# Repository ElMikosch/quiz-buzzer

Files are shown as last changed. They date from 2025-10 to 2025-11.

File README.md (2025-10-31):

# Quiz Buzzer System

A distributed ESP32-based quiz buzzer system with 4 wireless buzzer nodes and a main controller for quiz game management.

## Features

- **4 Independent Buzzer Nodes**: Wireless ESP32-based buttons with LED feedback
- **First-Press Detection**: Reliable distributed timing across all buzzers
- **Game State Management**: Ready, locked, and partial-lockout states
- **Auto-Reconnection**: Automatic state recovery after power cycle or network issues
- **Connection Monitoring**: Heartbeat system detects disconnections within 5 seconds
- **Answer Validation**: Correct/wrong/reset controls for game host
- **PC Integration**: USB serial interface (115200 baud) for quiz software
- **Visual Feedback**: LED states (solid=ready, blink=selected, off=locked, rapid blink=disconnected)
- **Low Latency**: Sub-100ms response time via ESP-NOW protocol
- **Battery Powered Buzzers**: ~4-6 hours operation with light sleep mode

## Hardware

- 5x Lolin32 Lite (ESP32) boards
- 7x Push buttons
- 4x LEDs with resistors
- 4x 1100mAh 3.7V LiPo batteries
- 1x USB cable

## Quick Start

### 1. Flash Firmware
```bash
# Flash main controller
pio run -e main_controller -t upload

# Flash each buzzer node
pio run -e buzzer_node_1 -t upload
pio run -e buzzer_node_2 -t upload
pio run -e buzzer_node_3 -t upload
pio run -e buzzer_node_4 -t upload
```

### 2. Label Boards
Physically label each board after flashing:
- Main controller: "MAIN"
- Buzzer nodes: "Buzzer 1" through "Buzzer 4"

### 3. Test System
1. Power main controller first
2. Power all buzzer nodes
3. All LEDs should turn on (ready state)
4. Press any buzzer → that LED blinks, others turn off
5. Press CORRECT button → all LEDs turn on again

### 4. Connect to PC
```bash
# Linux/Mac
screen /dev/ttyUSB0 115200

# Windows
# Use PuTTY or Arduino Serial Monitor at 115200 baud
```

## Documentation

- **[GPIO Pins](docs/GPIO_PINS.md)** - Pin assignments and hardware requirements
- **[Protocols](docs/PROTOCOLS.md)** - ESP-NOW and USB Serial protocols
- **[State Machine](docs/STATE_MACHINE.md)** - Game states and transitions
- **[Deployment](docs/DEPLOYMENT.md)** - Full deployment and troubleshooting guide

## PC Interface

### Outbound Messages (Controller → PC)

Messages sent over USB serial (newline-terminated):
```
BUZZER:1      # Buzzer 1 pressed
BUZZER:2      # Buzzer 2 pressed
BUZZER:3      # Buzzer 3 pressed
BUZZER:4      # Buzzer 4 pressed
CORRECT       # Correct answer button pressed
WRONG         # Wrong answer button pressed
RESET         # Reset button pressed
DISCONNECT:2  # Buzzer 2 disconnected
RECONNECT:2   # Buzzer 2 reconnected
```

### Inbound Commands (PC → Controller)

Send commands to control the game from your PC:
```
CORRECT\n     # Mark answer correct and reset game
WRONG\n       # Mark answer wrong and lock out current buzzer
RESET\n       # Full reset of game state
```

Command responses:
```
CMD_ACK:CORRECT           # Command acknowledged and executed
CMD_ACK:WRONG             # Command acknowledged and executed
CMD_ACK:RESET             # Command acknowledged and executed
CMD_ERR:UNKNOWN:FOO       # Unknown command "FOO"
CMD_ERR:BUFFER_OVERFLOW   # Input exceeded 256 bytes
```

### Example: Reading Messages
```python
import serial
ser = serial.Serial('/dev/ttyUSB0', 115200)
while True:
    line = ser.readline().decode().strip()
    if line.startswith('BUZZER:'):
        buzzer_id = int(line.split(':')[1])
        print(f"Buzzer {buzzer_id} pressed!")
    elif line == 'CORRECT':
        print("Correct answer!")
```

### Example: Sending Commands
```python
import serial
ser = serial.Serial('/dev/ttyUSB0', 115200)

# Mark answer correct
ser.write(b'CORRECT\n')
response = ser.readline().decode().strip()
print(response)  # CMD_ACK:CORRECT

# Mark answer wrong
ser.write(b'WRONG\n')
response = ser.readline().decode().strip()
print(response)  # CMD_ACK:WRONG

# Reset game
ser.write(b'RESET\n')
response = ser.readline().decode().strip()
print(response)  # CMD_ACK:RESET
```

### Using with Serial Terminal
```bash
# Linux/Mac - using screen
screen /dev/ttyUSB0 115200
# Type commands: CORRECT, WRONG, or RESET followed by Enter

# Alternative - using echo
echo "CORRECT" > /dev/ttyUSB0

# Windows PowerShell
"CORRECT`n" | Out-File -FilePath COM3 -Encoding ASCII -NoNewline
```

**Note**: Serial commands work identically to physical button presses and can be used concurrently.

## Project Structure

```
quiz-buzzer/
├── src/
│   ├── buzzer_node.cpp    # Buzzer node firmware
│   ├── controller.cpp     # Main controller firmware
│   ├── protocol.h         # Shared message protocol
│   ├── config.h           # Pin assignments and constants
│   └── main.cpp           # Entry point (empty, routing via platformio.ini)
├── docs/
│   ├── GPIO_PINS.md       # Hardware pin assignments
│   ├── PROTOCOLS.md       # Communication protocols
│   ├── STATE_MACHINE.md   # Game state documentation
│   └── DEPLOYMENT.md      # Deployment and troubleshooting
├── openspec/              # Design proposals and specs
└── platformio.ini         # Build configurations
```

## Building

### Prerequisites
- [PlatformIO](https://platformio.org/install)
- USB drivers for Lolin32 Lite (CH340 or CP2102)

### Build Commands
```bash
# Build all environments
pio run

# Build specific environment
pio run -e main_controller
pio run -e buzzer_node_1

# Build and upload
pio run -e main_controller -t upload

# Monitor serial output
pio device monitor -e main_controller
```

## Troubleshooting

### Buzzer LEDs Not Responding
- Verify custom MAC addresses in serial output (AA:BB:CC:DD:EE:00-04)
- Check ESP-NOW initialization messages
- Ensure main controller powered first
- Reduce distance between boards

### Button Presses Not Detected
- Test button continuity with multimeter
- Check GPIO pin assignments match wiring
- Verify internal pullups enabled (default)

### No Serial Messages to PC
- Check baud rate is 115200
- Verify USB drivers installed
- Check serial port permissions (Linux: add user to `dialout` group)
- Ensure main controller receiving buzzer presses (check local serial)

### Buzzer Shows Rapid Blinking (10Hz)
- This indicates disconnection from main controller
- Check main controller is powered and running
- Verify both devices on same WiFi channel (channel 1)
- Move buzzer closer to main controller (within ~20m)
- Check serial output on main controller for `DISCONNECT:<id>` messages
- Buzzer will auto-reconnect when heartbeat resumes

### Buzzer Reconnects But Wrong LED State
- System automatically syncs state on reconnection
- Check serial output for `STATE_SYNC` messages
- If issue persists, press RESET button on main controller to clear all state

### Build Errors
- Ensure PlatformIO is updated: `pio upgrade`
- Clean build: `pio run -t clean`
- Check that correct environment is selected

See **[docs/DEPLOYMENT.md](docs/DEPLOYMENT.md)** for detailed troubleshooting.

## Future Enhancements

- [ ] Speaker audio feedback on buzzer nodes (GPIO 14 reserved)
- [ ] Low battery voltage monitoring
- [ ] Visual display screen
- [ ] Over-the-air (OTA) firmware updates
- [ ] DIP switch node ID configuration
- [ ] Auto-discovery of buzzer nodes

## License

MIT License - See LICENSE file for details

## Contributing

This project uses OpenSpec for change proposals. See `openspec/AGENTS.md` for guidelines on creating proposals.

## Support

For issues and questions, open an issue on GitHub.

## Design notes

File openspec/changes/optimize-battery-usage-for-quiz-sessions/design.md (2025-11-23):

# Technical Design: Battery Usage Optimization

## Context

The quiz buzzer system runs on battery-powered ESP32 nodes that must operate throughout quiz sessions (30-60 minutes typical). Current implementation consumes excessive power due to:
- Full-speed CPU operation (240MHz)
- Always-active WiFi without modem sleep
- Continuous polling loop with minimal delay (1ms)
- No sleep modes between operations

Human reaction time (150-300ms average, 100ms for fast reflexes) provides headroom for modest latency additions while maintaining quiz fairness. Commercial quiz systems typically have 20-50ms latency; we target <50ms to stay competitive while optimizing battery life.

## Goals / Non-Goals

**Goals:**
- Reduce power consumption by 50-70% during active quiz sessions
- Maintain button press response time <50ms for fairness
- Ensure equal latency across all nodes (±5ms variance)
- Extend battery life from hours to full-day operation
- Preserve all existing functionality and LED behaviors

**Non-Goals:**
- Deep sleep modes (incompatible with sub-second response requirements)
- Battery monitoring/fuel gauge (future enhancement)
- Dynamic heartbeat adjustment based on activity
- Power optimization for main controller (remains USB-powered)
- Adaptive power modes based on battery level

## Decisions

### Decision 1: Light Sleep Instead of Deep Sleep
**Choice:** Use ESP32 light sleep mode with GPIO wake on button press.

**Rationale:**
- Light sleep wakes in ~3-5ms vs deep sleep's 100-300ms
- GPIO interrupt wake provides immediate response to button press
- WiFi and ESP-NOW connection state preserved (no reconnection delay)
- Timer wake allows periodic processing (LED updates, heartbeat checks)

**Alternatives considered:**
- Deep sleep: Rejected due to 100-300ms wake time violating <50ms requirement
- No sleep: Current approach, unacceptable battery consumption
- Active waiting with yield(): Minimal power savings compared to light sleep

### Decision 2: CPU Frequency Reduction to 80MHz
**Choice:** Reduce CPU from default 240MHz to 80MHz.

**Rationale:**
- ESP32 power consumption scales roughly linearly with frequency
- 80MHz provides 66% reduction from 240MHz (saves ~40% CPU power)
- More than adequate for simple embedded logic (GPIO, ESP-NOW, PWM)
- Arduino timing functions (millis/micros) remain accurate
- ESP-NOW and WiFi drivers work correctly at 80MHz

**Alternatives considered:**
- 160MHz: Less power savings, no performance benefit needed
- 40MHz: Potential WiFi/ESP-NOW reliability issues
- Dynamic scaling: Added complexity without clear benefit for this use case

### Decision 3: WiFi Modem Sleep Mode
**Choice:** Enable `WIFI_PS_MIN_MODEM` power save mode.

**Rationale:**
- WiFi radio is largest power consumer on ESP32
- Modem sleep shuts down RF between packets while maintaining connection
- Automatic wake on ESP-NOW TX/RX (transparent to application)
- Adds 5-10ms latency (acceptable within 50ms budget)
- No code changes needed beyond configuration call

**Alternatives considered:**
- `WIFI_PS_MAX_MODEM`: More aggressive sleep, but can cause packet loss
- `WIFI_PS_NONE`: Current default, no power savings
- Disable WiFi between heartbeats: Complex state management, connection reliability issues

### Decision 4: Dynamic Power Modes Based on Game State
**Choice:** Implement three power modes with different sleep durations:
- **ACTIVE** (ready state): 50ms sleep, GPIO wake enabled
- **LOW_POWER** (locked out): 100ms sleep, GPIO wake disabled
- **MINIMAL** (disconnected): 200ms sleep, GPIO wake disabled

**Rationale:**
- Ready state needs fast response, justify shorter sleep (50ms)
- Locked/disconnected states can sleep longer (button inactive)
- Breathing LED fade (20ms updates) works fine with 200ms wake interval
- State transitions occur naturally with LED commands
- Significant power savings during non-active periods

**Alternatives considered:**
- Single sleep duration: Misses optimization opportunity during locked/disconnected
- Five+ power modes: Complexity without proportional benefit
- Activity-based adaptation: Over-engineered for predictable quiz usage patterns

### Decision 5: Timer Wake as Fallback to GPIO Wake
**Choice:** Always configure both GPIO wake (button) and timer wake (backup) for light sleep.

**Rationale:**
- GPIO wake handles button presses immediately (<5ms)
- Timer wake ensures periodic processing even if no button press
- Required for LED updates (blink/fade), heartbeat monitoring, ESP-NOW RX
- 50ms timer wake in ready state ensures <50ms worst-case button latency
- Longer timers (100-200ms) acceptable when button inactive

**Alternatives considered:**
- GPIO wake only: Would miss heartbeats and LED updates
- Timer wake only: Higher power consumption, slower button response
- Event-driven ESP-NOW wake: Not reliably supported in light sleep

## Architecture

### Power State Machine

```
           [Startup]
               |
               v
        [MINIMAL MODE]
        LED: breathing
        Sleep: 200ms
        GPIO wake: disabled
               |
               | (receive heartbeat + state sync → ready)
               v
        [ACTIVE MODE] <----------+
        LED: solid on            |
        Sleep: 50ms              |
        GPIO wake: enabled       | (reset/correct button)
               |                 |
               | (wrong answer / locked out)
               v                 |
        [LOW_POWER MODE]         |
        LED: off                 |
        Sleep: 100ms             |
        GPIO wake: disabled -----+
```

### Loop Execution Flow

```
loop() iteration:
1. Check connection (heartbeat timeout)
2. Handle button press (if GPIO wake triggered)
3. Update LED (blink/fade state machine)
4. Determine current power mode from LED state
5. Configure sleep (GPIO + timer wake sources)
6. Enter light sleep
7. Wake on button press OR timer expiry
8. Repeat
```

### Timing Budget Analysis

| Operation | Time (ms) | Notes |
|---|---|---|
| Light sleep wake | 3-5 | GPIO interrupt wake |
| Button debounce | 0-50 | Max debounce delay |
| ESP-NOW transmission | 5-10 | With modem sleep wake |
| Loop processing overhead | 1-2 | GPIO read, LED update |
| **Total worst case** | **59-67** | **Exceeds 50ms target** |

**Mitigation:** Reduce debounce delay from 50ms to 30ms in active mode, bringing total to 39-47ms.

## Risks / Trade-offs

### Risk 1: Light Sleep Compatibility with ESP-NOW Reception
**Risk:** ESP-NOW messages might not reliably wake ESP32 from light sleep.

**Mitigation:** 
- Timer wake every 50ms ensures messages processed within reasonable time
- Heartbeat interval (2000ms) >> sleep duration (50ms), plenty of margin
- Test message reception reliability extensively during implementation

### Risk 2: Timing Variance Across Nodes
**Risk:** Power mode transitions could cause temporary timing differences between nodes.

**Mitigation:**
- All nodes transition together (synchronized by main controller LED commands)
- Test simultaneous button presses during state transitions
- Log timing measurements to verify fairness (±5ms target)

### Risk 3: PWM/LED Behavior at Reduced CPU Frequency
**Risk:** LED PWM might flicker or lose precision at 80MHz.

**Mitigation:**
- LEDC peripheral uses independent clock, not affected by CPU frequency
- Test all LED patterns (solid, blink, fade) after frequency change
- Measure PWM frequency/duty cycle with oscilloscope if issues arise

### Risk 4: Reduced Button Debounce Time
**Risk:** 30ms debounce might allow switch bounce through, causing double presses.

**Mitigation:**
- Test with all 4 physical buzzer buttons extensively
- Monitor serial logs for unexpected multiple presses within short time
- Can increase debounce if bounce detected (trade latency vs reliability)
- Add "burst suppression" (ignore presses within 100ms of previous press)

## Migration Plan

**Phase 1: Non-Breaking Power Optimizations**
1. Add CPU frequency scaling (always safe, test timing)
2. Enable WiFi modem sleep (transparent to application)
3. Add telemetry: log current measurements, button latency

**Phase 2: Light Sleep Implementation**
1. Add light sleep with conservative 50ms duration in all modes
2. Test button responsiveness and message reception
3. Monitor for any missed heartbeats or state sync issues

**Phase 3: Dynamic Power Modes**
1. Implement power mode state machine
2. Add longer sleep durations for locked/disconnected states
3. Test state transitions and timing fairness

**Rollback:** Each phase can be individually disabled via config constants if issues arise.

## Open Questions

1. **Optimal debounce time:** Is 30ms sufficient, or do we need 40-50ms? Requires hardware testing.
2. **Battery capacity selection:** What mAh capacity should be recommended for target full-day operation? Depends on measured power consumption.
3. **Sleep duration tuning:** Are 50/100/200ms optimal, or should we adjust based on measured latency? Will iterate during testing.
4. **Main controller optimization:** Should main controller also reduce CPU frequency (doesn't affect battery life but reduces heat)? Could add in future.

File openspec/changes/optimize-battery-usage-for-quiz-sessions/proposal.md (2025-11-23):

# Battery Usage Optimization for Quiz Sessions

## Why
The buzzer nodes run exclusively on battery power during quiz sessions, but currently consume excessive power due to always-active WiFi, full-speed CPU operation, and continuous polling loops. This results in short battery life and frequent recharging. However, human reaction times (150-300ms) and quiz system requirements allow for moderate latency (30-80ms) as long as the first button press is always detected correctly and fairly across all nodes.

## What Changes
- **Add light sleep mode** to buzzer nodes between loop iterations with GPIO interrupt wake on button press
- **Add CPU frequency scaling** from 240MHz to 80MHz during normal operation (40% less power)
- **Add WiFi modem sleep** to reduce power consumption between ESP-NOW transmissions
- **Add dynamic power modes** based on game state (ready vs locked/disconnected)
- **Maintain response time guarantee** of <50ms button press detection for quiz fairness
- **Add power state transitions** for entering/exiting low-power modes based on game events

## Impact
- **Affected specs**: buzzer-node, main-controller
- **Affected code**: 
  - `src/buzzer_node.cpp`: Add power management, sleep modes, interrupt handlers
  - `src/config.h`: Add power management constants and thresholds
  - `src/controller.cpp`: Optimize heartbeat timing for power efficiency
- **Expected outcomes**:
  - 50-70% reduction in power consumption during quiz sessions
  - Maintained <50ms button press response time (well within human reaction time variance)
  - Equal latency across all nodes preserving quiz fairness
  - Extended battery life from hours to full-day operation
- **Non-goals**:
  - Deep sleep modes (incompatible with sub-second wake requirements)
  - Battery monitoring/reporting (future enhancement)
  - Dynamic heartbeat adjustment (keep simple for v1)

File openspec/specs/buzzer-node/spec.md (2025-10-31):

# buzzer-node Specification

## Purpose
TBD - created by archiving change add-multi-board-buzzer-system. Update Purpose after archive.
## Requirements
### Requirement: Button Press Detection
Each buzzer node SHALL detect button press events with debouncing and transmit them to the main controller.

#### Scenario: Button press detected
- **WHEN** a player presses the buzzer button
- **THEN** the node SHALL debounce the input for 50ms
- **AND** transmit a button press message to the main controller
- **AND** include node ID (1-4) and timestamp in the message

#### Scenario: Button already pressed during lockout
- **WHEN** a player presses the buzzer button
- **AND** the node is in locked-out state (LED off)
- **THEN** the node SHALL ignore the button press
- **AND** NOT transmit any message

#### Scenario: Rapid repeated presses
- **WHEN** a player presses the buzzer multiple times rapidly
- **THEN** the node SHALL debounce each press
- **AND** transmit at most one message per 100ms

### Requirement: LED Visual Feedback
Each buzzer node SHALL control an LED to indicate the current game state based on commands from the main controller, using PWM-based brightness control for smooth visual effects.

#### Scenario: Ready state - LED solid on
- **WHEN** the game is in ready state
- **AND** the node is connected to main controller
- **THEN** the LED SHALL be continuously lit at full brightness (PWM duty cycle 255)
- **AND** the button SHALL be active

#### Scenario: Disconnected state - LED breathing effect
- **WHEN** the node is disconnected from main controller
- **THEN** the LED SHALL display a smooth breathing effect (fade in and out)
- **AND** use PWM to gradually increase brightness from 0 to 255
- **AND** use PWM to gradually decrease brightness from 255 to 0
- **AND** create a continuous breathing pattern until connection is restored
- **AND** the button SHALL be inactive

#### Scenario: Selected buzzer - two-stage blink pattern
- **WHEN** this buzzer was the first to press
- **AND** the main controller has acknowledged the press
- **THEN** the LED SHALL blink rapidly at 5Hz (100ms on, 100ms off) for exactly 3 seconds
- **AND** after 3 seconds the LED SHALL transition to slow blink at 2Hz (500ms on, 500ms off)
- **AND** continue slow blinking until game state changes
- **AND** the button SHALL be inactive

#### Scenario: Locked out - LED off
- **WHEN** this buzzer gave a wrong answer
- **THEN** the LED SHALL be off (PWM duty cycle 0)
- **AND** the button SHALL be inactive

#### Scenario: Other buzzer selected - LED off
- **WHEN** a different buzzer was first to press
- **THEN** the LED SHALL be off (PWM duty cycle 0)
- **AND** the button SHALL be inactive

### Requirement: PWM LED Control
Each buzzer node SHALL use ESP32 LEDC (PWM) peripheral to control LED brightness for smooth visual effects.

#### Scenario: PWM initialization at startup
- **WHEN** the node powers on
- **THEN** it SHALL configure LEDC channel 0 with 5kHz frequency and 8-bit resolution
- **AND** attach the LED pin to the PWM channel
- **AND** verify PWM initialization succeeds before continuing

#### Scenario: Smooth breathing fade implementation
- **WHEN** in disconnected state with breathing effect active
- **THEN** the node SHALL update LED brightness in small increments (fade steps)
- **AND** create smooth transitions between brightness levels
- **AND** use timing control to achieve visible breathing rate (~2-3 seconds per full cycle)
- **AND** ensure no visible flicker or stuttering

#### Scenario: Fast-to-slow blink transition timing
- **WHEN** transitioning from fast blink to slow blink after 3 seconds
- **THEN** the node SHALL track elapsed time from fast-blink start
- **AND** switch blink interval from 100ms to 500ms exactly at 3-second mark
- **AND** maintain blink state continuity during transition (no glitches)

### Requirement: ESP-NOW Communication
Each buzzer node SHALL communicate with the main controller using ESP-NOW protocol.

#### Scenario: Successful message transmission
- **WHEN** transmitting a button press message
- **THEN** the node SHALL use ESP-NOW unicast to the main controller MAC address
- **AND** retry up to 3 times if transmission fails
- **AND** wait 10ms between retries

#### Scenario: Receiving LED command
- **WHEN** receiving an LED command from the main controller
- **THEN** the node SHALL validate the message format
- **AND** update the LED state (on/off/blink)
- **AND** apply the change within 50ms

#### Scenario: Communication timeout
- **WHEN** no message received from main controller for 5 seconds
- **THEN** the node SHALL enter error state
- **AND** blink LED rapidly (5Hz) to indicate communication error

### Requirement: Node Identification
Each buzzer node SHALL have a unique identifier (1-4) configured in firmware.

#### Scenario: Node ID in messages
- **WHEN** transmitting any message
- **THEN** the node SHALL include its configured ID (1-4)
- **AND** the ID SHALL be immutable at runtime

#### Scenario: Node ID from build configuration
- **WHEN** the firmware is compiled
- **THEN** the node ID SHALL be set via build flag (NODE_ID)
- **AND** the ID SHALL be validated to be in range 1-4

### Requirement: Custom MAC Address
Each buzzer node SHALL set a custom MAC address based on its node ID to simplify configuration.

#### Scenario: MAC address assignment
- **WHEN** the node powers on
- **THEN** it SHALL set its MAC address to {0xAA, 0xBB, 0xCC, 0xDD, 0xEE, NODE_ID}
- **AND** use esp_wifi_set_mac() before ESP-NOW initialization
- **AND** print the custom MAC address to Serial

#### Scenario: MAC address verification
- **WHEN** ESP-NOW is initialized
- **THEN** the custom MAC address SHALL be active
- **AND** visible to the main controller
- **AND** match the expected pattern (ending in 0x01-0x04)

### Requirement: Power-On Initialization
Each buzzer node SHALL initialize hardware and communication on power-up.

#### Scenario: Successful initialization
- **WHEN** the node powers on
- **THEN** it SHALL initialize GPIO pins (button input with pullup, LED output)
- **AND** reserve a GPIO pin for future speaker integration (not implemented)
- **AND** initialize PWM/LEDC for LED control
- **AND** set custom MAC address based on NODE_ID
- **AND** initialize ESP-NOW with main controller MAC address
- **AND** set LED to breathing fade (disconnected state until first heartbeat)
- **AND** print initialization status to Serial at 115200 baud
- **AND** include node ID and custom MAC address in output

#### Scenario: Initialization failure
- **WHEN** ESP-NOW initialization fails
- **THEN** the node SHALL blink LED rapidly (10Hz)
- **AND** print error to Serial
- **AND** retry initialization every 5 seconds

### Requirement: Connection Monitoring
Each buzzer node SHALL monitor its connection to the main controller and detect disconnections.

#### Scenario: Normal heartbeat reception
- **WHEN** the node receives a heartbeat message from the main controller
- **THEN** it SHALL update its last-heartbeat timestamp
- **AND** maintain normal operation with current LED state

#### Scenario: Connection timeout detected
- **WHEN** no heartbeat received for CONNECTION_TIMEOUT_MS (5000ms)
- **THEN** the node SHALL enter disconnected state
- **AND** set LED to breathing fade effect (not rapid blink)
- **AND** disable button presses
- **AND** log disconnection event to Serial

#### Scenario: Heartbeat received after timeout
- **WHEN** in disconnected state
- **AND** a heartbeat message is received
- **THEN** the node SHALL detect reconnection
- **AND** send MSG_STATE_REQUEST to main controller
- **AND** wait for state sync before updating LED
- **AND** log reconnection event to Serial

### Requirement: State Synchronization
Each buzzer node SHALL request and receive current game state when reconnecting, interpreting the game state mode to determine correct LED behavior.

#### Scenario: Receive state sync message (MODIFIED)
- **WHEN** receiving MSG_STATE_SYNC from main controller
- **THEN** the node SHALL extract game state from the value field:
  - Bits 0-3: locked buzzers bitmask
  - Bits 4-6: selected buzzer ID (0 = none)
  - Bit 7: game state mode (0 = LOCKED/READY, 1 = PARTIAL_LOCKOUT)
- **AND** determine if this node is locked: `isLocked = lockedBuzzers & (1 << (NODE_ID - 1))`
- **AND** determine if this node is selected: `isSelected = (selectedBuzzer == NODE_ID)`
- **AND** determine game state mode: `isPartialLockout = (value & 0x80) != 0`

#### Scenario: State sync LED logic for locked mode (ADDED)
- **WHEN** receiving state sync
- **AND** bit 7 = 0 (locked/ready mode)
- **AND** selectedBuzzer != 0 (locked state)
- **THEN** if this node is selected: set LED to BLINK (two-stage pattern)
- **AND** if this node is not selected: set LED to OFF
- **AND** restore normal operation

#### Scenario: State sync LED logic for partial lockout mode (ADDED)
- **WHEN** receiving state sync
- **AND** bit 7 = 1 (partial lockout mode)
- **THEN** if this node is selected: set LED to BLINK (two-stage pattern)
- **AND** if this node is in lockedBuzzers bitmask: set LED to OFF
- **AND** if this node is neither selected nor locked: set LED to ON
- **AND** restore normal operation

#### Scenario: State sync LED logic for ready state (ADDED)
- **WHEN** receiving state sync
- **AND** bit 7 = 0 (locked/ready mode)
- **AND** selectedBuzzer == 0 (ready state)
- **THEN** set LED to ON for all nodes
- **AND** restore normal operation

### Requirement: Power Cycle Recovery
Each buzzer node SHALL automatically recover correct state after power cycle.

#### Scenario: Power cycle during ready state
- **WHEN** node powers on
- **AND** main controller is in ready state
- **THEN** the node SHALL connect to main controller
- **AND** receive heartbeat within 5 seconds
- **AND** request state sync
- **AND** restore LED to on (ready state)

#### Scenario: Power cycle during locked state
- **WHEN** node powers on
- **AND** game is in locked state
- **THEN** the node SHALL request and receive current state
- **AND** restore correct LED (off if not selected, two-stage blink if selected)
- **AND** maintain proper button disable state

#### Scenario: Power cycle during partial lockout
- **WHEN** node powers on
- **AND** game is in partial lockout state
- **AND** this node is locked out
- **THEN** the node SHALL restore LED to off
- **AND** disable button presses

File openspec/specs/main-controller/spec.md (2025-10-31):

# main-controller Specification

## Purpose
Defines the behavior and responsibilities of the main controller board, which acts as the ESP-NOW hub, game state coordinator, physical control button interface, and bidirectional USB serial gateway for PC communication.
## Requirements
### Requirement: ESP-NOW Hub
The main controller SHALL receive messages from all 4 buzzer nodes using ESP-NOW.

#### Scenario: Receive button press from buzzer node
- **WHEN** a buzzer node transmits a button press message
- **THEN** the main controller SHALL receive the message
- **AND** extract the node ID and timestamp
- **AND** process the button press according to current game state

#### Scenario: Handle simultaneous messages
- **WHEN** multiple buzzer nodes transmit within 1ms
- **THEN** the main controller SHALL process messages in reception order
- **AND** use reception timestamp (micros()) for first-press determination

#### Scenario: Send LED command to buzzer node
- **WHEN** the game state changes
- **THEN** the main controller SHALL send LED commands to affected buzzer nodes
- **AND** use broadcast for "all LEDs on/off" commands
- **AND** use unicast for specific node LED commands

### Requirement: Control Button Interface
The main controller SHALL provide 3 physical buttons for game control.

#### Scenario: Correct answer button pressed
- **WHEN** the game master presses the "correct answer" button (button 1)
- **AND** a buzzer is currently selected
- **THEN** the controller SHALL send 'C' key to PC
- **AND** reset game state to ready
- **AND** turn on all buzzer LEDs

#### Scenario: Wrong answer button pressed
- **WHEN** the game master presses the "wrong answer" button (button 2)
- **AND** a buzzer is currently selected
- **THEN** the controller SHALL send 'W' key to PC
- **AND** lock out the currently selected buzzer
- **AND** turn off the locked buzzer's LED
- **AND** allow remaining buzzers to press again
- **AND** turn on LEDs for remaining active buzzers

#### Scenario: Reset button pressed
- **WHEN** the game master presses the "reset" button (button 3)
- **THEN** the controller SHALL send 'R' key to PC
- **AND** clear all game state (unlock all buzzers)
- **AND** turn on all buzzer LEDs
- **AND** return to ready state

#### Scenario: Control button pressed in invalid state
- **WHEN** correct or wrong button is pressed
- **AND** no buzzer is currently selected
- **THEN** the controller SHALL ignore the button press
- **AND** NOT send any key to PC

### Requirement: USB Serial Communication
The main controller SHALL send event messages to the PC via USB serial port.

#### Scenario: Buzzer press serial output
- **WHEN** a buzzer button press is registered
- **THEN** the controller SHALL send "BUZZER:<id>\n" to serial port
- **AND** <id> SHALL be the buzzer number (1-4)
- **AND** the message SHALL be newline-terminated

#### Scenario: Control button serial output
- **WHEN** a control button is pressed and action is taken
- **THEN** the controller SHALL send the corresponding message to serial port
- **AND** correct answer SHALL send "CORRECT\n"
- **AND** wrong answer SHALL send "WRONG\n"
- **AND** reset SHALL send "RESET\n"

#### Scenario: Serial baud rate
- **WHEN** the serial port is initialized
- **THEN** the baud rate SHALL be set to 115200
- **AND** use 8 data bits, no parity, 1 stop bit (8N1)

#### Scenario: Message queuing
- **WHEN** multiple events occur rapidly
- **THEN** messages SHALL be queued (up to 10 messages)
- **AND** sent in FIFO order
- **AND** oldest message discarded if queue is full

### Requirement: Serial Command Input Processing
The main controller SHALL accept and process control commands received via USB serial port from the PC, validating that commands are only executed in valid game states.

#### Scenario: Process CORRECT command from serial (MODIFIED)
- **WHEN** receiving "CORRECT\n" or "CORRECT\r\n" from serial port
- **AND** a buzzer is currently selected (selectedBuzzer != 0)
- **THEN** the controller SHALL call handleCorrectAnswer()
- **AND** send "CMD_ACK:CORRECT\n" acknowledgment
- **AND** execute identical behavior to physical CORRECT button press
- **AND** process the command within 10ms

#### Scenario: Process CORRECT command with no buzzer selected (ADDED)
- **WHEN** receiving "CORRECT\n" or "CORRECT\r\n" from serial port
- **AND** no buzzer is currently selected (selectedBuzzer == 0)
- **THEN** the controller SHALL ignore the command
- **AND** send "CMD_ACK:CORRECT\n" acknowledgment
- **AND** log "No buzzer selected, ignoring CORRECT command" to Serial
- **AND** NOT change game state
- **AND** NOT send any message to PC interface

#### Scenario: Process WRONG command from serial (MODIFIED)
- **WHEN** receiving "WRONG\n" or "WRONG\r\n" from serial port
- **AND** a buzzer is currently selected (selectedBuzzer != 0)
- **THEN** the controller SHALL call handleWrongAnswer()
- **AND** send "CMD_ACK:WRONG\n" acknowledgment
- **AND** execute identical behavior to physical WRONG button press
- **AND** process the command within 10ms

#### Scenario: Process WRONG command with no buzzer selected (ADDED)
- **WHEN** receiving "WRONG\n" or "WRONG\r\n" from serial port
- **AND** no buzzer is currently selected (selectedBuzzer == 0)
- **THEN** the controller SHALL ignore the command
- **AND** send "CMD_ACK:WRONG\n" acknowledgment
- **AND** log "No buzzer selected, ignoring WRONG command" to Serial
- **AND** NOT change game state
- **AND** NOT send any message to PC interface

### Requirement: Power-On Initialization
The main controller SHALL initialize all subsystems on power-up.

#### Scenario: Successful initialization
- **WHEN** the controller powers on
- **THEN** it SHALL initialize GPIO pins for 3 control buttons (with pullups)
- **AND** initialize ESP-NOW as receiver for 4 buzzer nodes
- **AND** initialize USB serial at 115200 baud
- **AND** broadcast "all LEDs on" command to buzzer nodes
- **AND** print initialization status to Serial at 115200 baud

#### Scenario: Initialization failure
- **WHEN** any subsystem fails to initialize
- **THEN** the controller SHALL print error details to Serial
- **AND** retry initialization every 5 seconds
- **AND** continue with partial functionality if possible

### Requirement: MAC Address Management
The main controller SHALL maintain the MAC addresses of all 4 buzzer nodes for bidirectional communication.

#### Scenario: MAC addresses configured
- **WHEN** the firmware is compiled
- **THEN** it SHALL include hardcoded MAC addresses for buzzer nodes 1-4
- **AND** use these addresses for unicast LED commands

#### Scenario: Message from unknown MAC
- **WHEN** receiving an ESP-NOW message from an unknown MAC address
- **THEN** the controller SHALL ignore the message
- **AND** log the unknown MAC to Serial

### Requirement: Watchdog and Recovery
The main controller SHALL implement watchdog timer for automatic recovery from crashes.

#### Scenario: Normal operation
- **WHEN** the controller is operating normally
- **THEN** it SHALL reset the watchdog timer every loop iteration
- **AND** the watchdog timeout SHALL be set to 5 seconds

#### Scenario: Crash or hang
- **WHEN** the watchdog timer expires (no reset for 5 seconds)
- **THEN** the ESP32 SHALL automatically reset
- **AND** reinitialize all subsystems
- **AND** return to ready state

### Requirement: Heartbeat Broadcasting
The main controller SHALL broadcast periodic heartbeat messages to all buzzer nodes.

#### Scenario: Periodic heartbeat transmission
- **WHEN** the controller is operating
- **THEN** it SHALL broadcast MSG_HEARTBEAT every 2000ms
- **AND** use ESP-NOW broadcast address (FF:FF:FF:FF:FF:FF)
- **AND** include timestamp in heartbeat message

#### Scenario: Heartbeat during all game states
- **WHEN** heartbeat interval expires
- **AND** game is in any state (ready/locked/partial lockout)
- **THEN** the heartbeat SHALL be sent
- **AND** NOT interfere with other message processing

### Requirement: Connection Status Tracking
The main controller SHALL track connection status of each buzzer node.

#### Scenario: Track last-seen timestamp
- **WHEN** receiving any message from a buzzer node
- **THEN** the controller SHALL update that node's last-seen timestamp
- **AND** mark the node as connected if previously disconnected

#### Scenario: Detect node disconnection
- **WHEN** no message received from a node for 5000ms
- **THEN** the controller SHALL mark the node as disconnected
- **AND** log disconnection event to Serial with node ID
- **AND** continue normal operation for other nodes

#### Scenario: Detect node reconnection
- **WHEN** receiving message from previously disconnected node
- **THEN** the controller SHALL mark node as connected
- **AND** log reconnection event to Serial with node ID
- **AND** wait for state sync request

### Requirement: State Synchronization Protocol
The main controller SHALL respond to state sync requests with current game state, including game state mode to distinguish between full lockout and partial lockout states.

#### Scenario: State sync message format (MODIFIED)
- **WHEN** sending MSG_STATE_SYNC to a buzzer node
- **THEN** the controller SHALL pack game state into the value field as follows:
  - Bits 0-3: locked buzzers bitmask (bit 0 = buzzer 1, bit 1 = buzzer 2, etc.)
  - Bits 4-6: selected buzzer ID (0-4, where 0 = none selected)
  - Bit 7: game state mode (0 = LOCKED/READY, 1 = PARTIAL_LOCKOUT)
- **AND** bit 7 SHALL be set to 1 when in STATE_PARTIAL_LOCKOUT
- **AND** bit 7 SHALL be set to 0 when in STATE_LOCKED or STATE_READY

#### Scenario: State sync in locked state (MODIFIED)
- **WHEN** node requests state sync
- **AND** game is in locked state
- **THEN** the controller SHALL send state sync with bit 7 = 0 (locked mode)
- **AND** send selectedBuzzer ID in bits 4-6
- **AND** send lockedBuzzers bitmask in bits 0-3 (may be 0x00)
- **AND** the buzzer node will interpret: selected buzzer gets BLINK, all others get OFF

#### Scenario: State sync in partial lockout (MODIFIED)
- **WHEN** node requests state sync
- **AND** game is in partial lockout state
- **THEN** the controller SHALL send state sync with bit 7 = 1 (partial lockout mode)
- **AND** send selectedBuzzer ID in bits 4-6
- **AND** send lockedBuzzers bitmask in bits 0-3
- **AND** the buzzer node will interpret: selected gets BLINK, locked get OFF, others get ON

#### Scenario: State sync in ready state (ADDED)
- **WHEN** node requests state sync
- **AND** game is in ready state
- **THEN** the controller SHALL send state sync with bit 7 = 0
- **AND** send selectedBuzzer = 0 in bits 4-6
- **AND** send lockedBuzzers = 0x00 in bits 0-3
- **AND** the buzzer node will interpret: all buzzers get ON

### Requirement: Reconnection Event Logging
The main controller SHALL log connection status changes via USB Serial.

#### Scenario: Log disconnection event
- **WHEN** a buzzer node disconnects (timeout)
- **THEN** the controller SHALL send "DISCONNECT:<node_id>\n" to serial
- **AND** include timestamp

#### Scenario: Log reconnection event
- **WHEN** a buzzer node reconnects
- **THEN** the controller SHALL send "RECONNECT:<node_id>\n" to serial
- **AND** include timestamp

#### Scenario: Log state sync event
- **WHEN** sending state sync to a reconnected node
- **THEN** the controller SHALL send "STATE_SYNC:<node_id>\n" to serial
- **AND** include current game state in log

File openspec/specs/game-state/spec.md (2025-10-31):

# game-state Specification

## Purpose
TBD - created by archiving change add-multi-board-buzzer-system. Update Purpose after archive.
## Requirements
### Requirement: Ready State
The game SHALL start in ready state where all buzzers can be pressed.

#### Scenario: System initialization to ready
- **WHEN** the system powers on or is reset
- **THEN** the game state SHALL be set to ready
- **AND** all 4 buzzers SHALL be active (can press)
- **AND** all 4 buzzer LEDs SHALL be lit
- **AND** no buzzer is selected

#### Scenario: Button press in ready state
- **WHEN** the game is in ready state
- **AND** a buzzer button is pressed
- **THEN** the game SHALL transition to locked state
- **AND** record the pressing buzzer as selected
- **AND** send the buzzer key (1-4) to PC
- **AND** make the selected buzzer LED blink
- **AND** turn off all other buzzer LEDs
- **AND** disable all buzzer buttons

### Requirement: Locked State
When a buzzer is selected, the game SHALL prevent further buzzer presses until an answer is judged.

#### Scenario: Correct answer from locked state
- **WHEN** in locked state with a selected buzzer
- **AND** the correct answer button is pressed
- **THEN** the game SHALL transition to ready state
- **AND** send 'C' key to PC
- **AND** turn on all buzzer LEDs
- **AND** enable all buzzer buttons
- **AND** clear the selected buzzer

#### Scenario: Wrong answer from locked state
- **WHEN** in locked state with a selected buzzer
- **AND** the wrong answer button is pressed
- **AND** at least 2 buzzers are still active
- **THEN** the game SHALL transition to partial lockout state
- **AND** send 'W' key to PC
- **AND** lock out the selected buzzer
- **AND** turn off the locked buzzer LED
- **AND** turn on remaining active buzzer LEDs
- **AND** enable remaining active buzzer buttons

#### Scenario: Wrong answer with only one buzzer remaining
- **WHEN** in locked state with a selected buzzer
- **AND** the wrong answer button is pressed
- **AND** only 1 buzzer is still active
- **THEN** the game SHALL lock out the last buzzer
- **AND** send 'W' key to PC
- **AND** remain in locked state (all buzzers locked)
- **AND** all LEDs SHALL be off

### Requirement: Partial Lockout State
After a wrong answer, the game SHALL allow remaining active buzzers to answer while keeping wrong buzzers locked out.

#### Scenario: Another buzzer press in partial lockout
- **WHEN** in partial lockout state
- **AND** an active buzzer button is pressed
- **THEN** the game SHALL transition to locked state
- **AND** record the new buzzer as selected
- **AND** send the buzzer key (1-4) to PC
- **AND** make the selected buzzer LED blink
- **AND** turn off active buzzer LEDs (keep locked LEDs off)

#### Scenario: Correct answer from partial lockout
- **WHEN** in partial lockout state with a selected buzzer
- **AND** the correct answer button is pressed
- **THEN** the game SHALL transition to ready state
- **AND** send 'C' key to PC
- **AND** unlock all buzzers
- **AND** turn on all buzzer LEDs
- **AND** enable all buzzer buttons

#### Scenario: Another wrong answer in partial lockout
- **WHEN** in partial lockout state with a selected buzzer
- **AND** the wrong answer button is pressed
- **THEN** the game SHALL lock out the selected buzzer
- **AND** send 'W' key to PC
- **AND** remain in partial lockout (or full lockout if last buzzer)
- **AND** continue allowing remaining active buzzers

### Requirement: Full Reset
The game SHALL support manual reset from any state to recover from errors or skip a question.

#### Scenario: Reset from any state
- **WHEN** the reset button is pressed
- **AND** the game is in any state (ready, locked, partial lockout)
- **THEN** the game SHALL transition to ready state
- **AND** send 'R' key to PC
- **AND** unlock all buzzers
- **AND** turn on all buzzer LEDs
- **AND** enable all buzzer buttons
- **AND** clear the selected buzzer

### Requirement: State Persistence
The game state SHALL be maintained in volatile memory and reset on power cycle, with automatic recovery for individual buzzer reconnections.

#### Scenario: Power cycle resets state
- **WHEN** the main controller loses power
- **AND** power is restored
- **THEN** the game SHALL initialize to ready state
- **AND** all previous state SHALL be cleared

#### Scenario: Buzzer reconnection preserves state
- **WHEN** a single buzzer node loses power or connection
- **AND** the main controller remains powered
- **THEN** the game state SHALL be preserved
- **AND** the reconnecting buzzer SHALL sync to current state
- **AND** other buzzers SHALL maintain their state
- **AND** gameplay SHALL continue normally

#### Scenario: Multiple buzzers reconnect
- **WHEN** multiple buzzer nodes reconnect simultaneously
- **THEN** each SHALL receive state sync independently
- **AND** the game state SHALL remain consistent
- **AND** all reconnected buzzers SHALL match current state

### Requirement: First-Press Adjudication
The game SHALL accurately determine which buzzer was pressed first when multiple presses occur close in time.

#### Scenario: Clear first press (>50ms gap)
- **WHEN** buzzer A is pressed
- **AND** buzzer B is pressed more than 50ms later
- **THEN** buzzer A SHALL be registered as first
- **AND** buzzer B press SHALL be ignored

#### Scenario: Simultaneous press (<1ms gap)
- **WHEN** multiple buzzers are pressed within 1ms
- **THEN** the buzzer whose message was received first SHALL be registered
- **AND** the tie SHALL be broken by reception timestamp (micros())
- **AND** subsequent presses SHALL be ignored

#### Scenario: Message reordering
- **WHEN** buzzer A presses first but message arrives second (network delay)
- **AND** buzzer B presses second but message arrives first
- **THEN** the message with earliest sender timestamp SHALL be used
- **AND** reception order SHALL be secondary tiebreaker

### Requirement: Locked Buzzer Tracking
The game SHALL track which buzzers are locked out and persist this through state transitions.

#### Scenario: Multiple wrong answers accumulate lockouts
- **WHEN** buzzer 1 gives wrong answer (locked out)
- **AND** buzzer 2 gives wrong answer (locked out)
- **AND** buzzer 3 presses (still active)
- **THEN** only buzzers 3 and 4 SHALL be active
- **AND** buzzers 1 and 2 SHALL remain locked

#### Scenario: Reset clears all lockouts
- **WHEN** multiple buzzers are locked out
- **AND** reset button is pressed
- **THEN** all buzzers SHALL be unlocked
- **AND** all buzzers SHALL become active

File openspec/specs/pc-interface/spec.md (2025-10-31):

# pc-interface Specification

## Purpose
Defines the bidirectional USB serial communication protocol between the main controller and PC, including outbound game state messages and inbound control commands.
## Requirements
### Requirement: USB Serial Communication
The main controller SHALL communicate with the PC via USB serial port using a text-based protocol.

#### Scenario: Serial port initialization
- **WHEN** the main controller powers on
- **THEN** the USB serial port SHALL initialize at 115200 baud
- **AND** use 8 data bits, no parity, 1 stop bit (8N1)
- **AND** be ready to send messages within 2 seconds

#### Scenario: PC recognizes serial device
- **WHEN** the main controller is connected via USB
- **THEN** the PC SHALL recognize it as a USB CDC serial device
- **AND** create a COM port (Windows) or /dev/ttyUSB or /dev/ttyACM device (Linux/Mac)
- **AND** no driver installation SHALL be required

### Requirement: Message Protocol Format
Messages SHALL be sent as newline-terminated ASCII text strings.

#### Scenario: Message framing
- **WHEN** any message is sent to the PC
- **THEN** it SHALL be ASCII text
- **AND** terminated with newline character ('\n')
- **AND** be human-readable for debugging

#### Scenario: Message types
- **WHEN** sending messages
- **THEN** the following message formats SHALL be used:
  - Buzzer press: "BUZZER:<id>\n" where <id> is 1-4
  - Correct answer: "CORRECT\n"
  - Wrong answer: "WRONG\n"
  - Reset: "RESET\n"

### Requirement: Buzzer Press Messages
When a buzzer is pressed and registered, the main controller SHALL send a buzzer message to the PC.

#### Scenario: Buzzer 1 pressed
- **WHEN** buzzer node 1 button is pressed and registered
- **THEN** the PC SHALL receive "BUZZER:1\n" via serial port

#### Scenario: Buzzer 2 pressed
- **WHEN** buzzer node 2 button is pressed and registered
- **THEN** the PC SHALL receive "BUZZER:2\n" via serial port

#### Scenario: Buzzer 3 pressed
- **WHEN** buzzer node 3 button is pressed and registered
- **THEN** the PC SHALL receive "BUZZER:3\n" via serial port

#### Scenario: Buzzer 4 pressed
- **WHEN** buzzer node 4 button is pressed and registered
- **THEN** the PC SHALL receive "BUZZER:4\n" via serial port

#### Scenario: Message timing
- **WHEN** a buzzer press is registered
- **THEN** the message SHALL be sent within 50ms
- **AND** arrive at PC within 100ms of button press

### Requirement: Control Button Messages
The three control buttons SHALL send corresponding messages to the PC.

#### Scenario: Correct answer button
- **WHEN** the correct answer button is pressed
- **AND** a buzzer is currently selected
- **THEN** the PC SHALL receive "CORRECT\n" via serial port

#### Scenario: Wrong answer button
- **WHEN** the wrong answer button is pressed
- **AND** a buzzer is currently selected
- **THEN** the PC SHALL receive "WRONG\n" via serial port

#### Scenario: Reset button
- **WHEN** the reset button is pressed
- **THEN** the PC SHALL receive "RESET\n" via serial port

### Requirement: Message Queuing
The system SHALL queue messages when multiple events occur rapidly.

#### Scenario: Normal message sending
- **WHEN** a single message is generated
- **AND** the serial port is not busy
- **THEN** the message SHALL be sent immediately

#### Scenario: Rapid multiple events
- **WHEN** multiple messages are generated in rapid succession
- **THEN** messages SHALL be queued in FIFO order
- **AND** the queue SHALL hold up to 10 messages
- **AND** messages SHALL be sent as soon as possible

#### Scenario: Queue overflow
- **WHEN** more than 10 messages are queued
- **THEN** the oldest message SHALL be discarded
- **AND** a debug message SHALL be logged to serial
- **AND** newer messages SHALL be preserved

### Requirement: Serial Connection Handling
The system SHALL handle serial connection and disconnection gracefully.

#### Scenario: USB connected at power-on
- **WHEN** the main controller powers on with USB connected
- **THEN** serial communication SHALL initialize within 2 seconds
- **AND** be ready to send messages

#### Scenario: USB disconnected during operation
- **WHEN** USB cable is disconnected
- **THEN** the game state SHALL continue to function normally
- **AND** messages SHALL be queued (up to 10 messages)
- **AND** ESP-NOW communication SHALL continue
- **AND** LED control SHALL continue to work

#### Scenario: USB reconnected
- **WHEN** USB cable is reconnected after disconnection
- **THEN** serial communication SHALL reinitialize within 2 seconds
- **AND** queued messages SHALL be sent in order
- **AND** new messages SHALL be sent immediately

### Requirement: PC Software Integration
The system SHALL provide serial messages compatible with quiz software or custom applications.

#### Scenario: Quiz software receives buzzer press
- **WHEN** a buzzer is pressed
- **AND** quiz software is reading the serial port
- **THEN** the software SHALL receive "BUZZER:<id>\n"
- **AND** be able to determine which player buzzed in
- **AND** the message SHALL arrive within 100ms of button press

#### Scenario: Quiz software receives control commands
- **WHEN** a control button is pressed (correct/wrong/reset)
- **AND** quiz software is reading the serial port
- **THEN** the software SHALL receive the corresponding message
- **AND** be able to trigger corresponding actions

#### Scenario: Message parsing
- **WHEN** the PC receives messages
- **THEN** each message SHALL be on a separate line
- **AND** be parseable by splitting on newline
- **AND** be extractable using simple string matching

### Requirement: Inbound Serial Commands
The main controller SHALL accept control commands from the PC via serial port to trigger game state changes.

#### Scenario: CORRECT command received
- **WHEN** the PC sends "CORRECT\n" via serial port
- **THEN** the main controller SHALL execute the correct answer action
- **AND** respond with "CMD_ACK:CORRECT\n"
- **AND** transition game state identically to pressing the physical CORRECT button
- **AND** process the command within 10ms of receipt

#### Scenario: WRONG command received
- **WHEN** the PC sends "WRONG\n" via serial port
- **THEN** the main controller SHALL execute the wrong answer action
- **AND** respond with "CMD_ACK:WRONG\n"
- **AND** transition game state identically to pressing the physical WRONG button
- **AND** process the command within 10ms of receipt

#### Scenario: RESET command received
- **WHEN** the PC sends "RESET\n" via serial port
- **THEN** the main controller SHALL execute the full reset action
- **AND** respond with "CMD_ACK:RESET\n"
- **AND** transition game state identically to pressing the physical RESET button
- **AND** process the command within 10ms of receipt

#### Scenario: Unknown command received
- **WHEN** the PC sends an unrecognized command
- **THEN** the main controller SHALL ignore the command
- **AND** respond with "CMD_ERR:UNKNOWN:<command>\n"
- **AND** NOT change game state
- **AND** continue normal operation

#### Scenario: Command with different line endings
- **WHEN** the PC sends a command terminated with '\n', '\r', or '\r\n'
- **THEN** the main controller SHALL accept all variations
- **AND** parse the command correctly
- **AND** execute the appropriate action

#### Scenario: Buffer overflow protection
- **WHEN** the PC sends data exceeding 256 bytes without a newline
- **THEN** the main controller SHALL discard the buffer
- **AND** send "CMD_ERR:BUFFER_OVERFLOW\n"
- **AND** continue normal operation without crashing

#### Scenario: Concurrent serial and button input
- **WHEN** a serial command arrives while button inputs are active
- **THEN** both input sources SHALL be processed correctly
- **AND** neither SHALL be blocked
- **AND** commands SHALL execute in the order received
- **AND** the system SHALL remain responsive to both input methods

#### Scenario: Serial command during different game states
- **WHEN** serial commands are received in READY, LOCKED, or PARTIAL_LOCKOUT state
- **THEN** commands SHALL execute with identical behavior to physical buttons
- **AND** respect game state rules (e.g., WRONG requires selected buzzer)
- **AND** produce the same LED patterns and state transitions

### Requirement: Diagnostic and Debug Output
The system SHALL provide debug information via the same serial port without interfering with protocol messages.

#### Scenario: Debug message format
- **WHEN** debug information needs to be output
- **THEN** debug messages SHALL be prefixed with "DEBUG: "
- **AND** be distinguishable from protocol messages
- **AND** allow quiz software to filter them out

#### Scenario: Initialization messages
- **WHEN** the system initializes
- **THEN** initialization status SHALL be output to serial
- **AND** include ESP-NOW status, GPIO configuration, and MAC addresses
- **AND** be prefixed with "DEBUG: " for filtering

#### Scenario: Error messages
- **WHEN** an error occurs (communication timeout, invalid state)
- **THEN** error details SHALL be output to serial
- **AND** be prefixed with "DEBUG: ERROR: "
- **AND** include timestamp and error description

### Requirement: Performance and Reliability
Serial communication SHALL be reliable and low-latency.

#### Scenario: Message latency
- **WHEN** any message is sent
- **THEN** it SHALL appear on the serial port within 10ms
- **AND** be received by PC software within 50ms (including USB latency)

#### Scenario: No message loss
- **WHEN** messages are sent at normal rate (<10/second)
- **THEN** all messages SHALL be successfully transmitted
- **AND** none SHALL be lost or corrupted

#### Scenario: Buffer overflow prevention
- **WHEN** the serial buffer fills up
- **THEN** the system SHALL not block
- **AND** use message queuing to handle backpressure
- **AND** discard oldest messages if necessary

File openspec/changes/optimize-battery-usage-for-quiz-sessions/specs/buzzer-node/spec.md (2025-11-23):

## ADDED Requirements

### Requirement: Power Mode Management
Each buzzer node SHALL implement dynamic power modes to optimize battery life while maintaining quiz fairness and response time guarantees.

#### Scenario: Active mode during ready state
- **WHEN** the node is connected and in ready state (LED solid on)
- **THEN** the node SHALL operate in active power mode
- **AND** maintain CPU frequency at 80MHz (reduced from default 240MHz)
- **AND** enable WiFi modem sleep between transmissions
- **AND** use light sleep with GPIO interrupt wake on button press
- **AND** guarantee button press detection within 50ms

#### Scenario: Low power mode during locked state
- **WHEN** the node is locked out (LED off, button inactive)
- **THEN** the node SHALL enter low power mode
- **AND** reduce CPU frequency to 80MHz
- **AND** enable WiFi modem sleep between heartbeat receptions
- **AND** disable button interrupt (button inactive)
- **AND** wake every 100ms to check for state change messages

#### Scenario: Minimal power mode during disconnected state
- **WHEN** the node is disconnected (LED breathing fade)
- **THEN** the node SHALL enter minimal power mode
- **AND** reduce CPU frequency to 80MHz
- **AND** enable WiFi modem sleep
- **AND** wake every 200ms for LED fade updates and heartbeat checking

### Requirement: Light Sleep with GPIO Interrupt
Each buzzer node SHALL use ESP32 light sleep mode with GPIO interrupt wake to reduce power consumption while maintaining rapid button response.

#### Scenario: Enter light sleep in ready state
- **WHEN** loop iteration completes
- **AND** node is in ready state with button active
- **THEN** the node SHALL configure GPIO wake on button press (LOW level)
- **AND** enter light sleep mode using esp_light_sleep_start()
- **AND** wake immediately on button press via GPIO interrupt
- **AND** wake on timer after maximum 50ms if no button press

#### Scenario: Button press wakes from light sleep
- **WHEN** in light sleep mode
- **AND** player presses the buzzer button
- **THEN** the GPIO interrupt SHALL wake the ESP32 within 5ms
- **AND** button press detection SHALL occur within 50ms total (including wake time)
- **AND** maintain debouncing logic after wake

#### Scenario: Timer wake from light sleep
- **WHEN** in light sleep mode
- **AND** no button press occurs
- **THEN** the node SHALL wake via timer after 50ms
- **AND** process LED updates, heartbeat checks, and ESP-NOW messages
- **AND** return to light sleep if button remains inactive

### Requirement: CPU Frequency Scaling
Each buzzer node SHALL reduce CPU frequency from default 240MHz to 80MHz to reduce power consumption while maintaining adequate performance for quiz operations.

#### Scenario: Set reduced CPU frequency at startup
- **WHEN** the node powers on
- **THEN** it SHALL call setCpuFrequencyMhz(80) during initialization
- **AND** verify frequency was set successfully
- **AND** adjust timing-sensitive operations if necessary
- **AND** log CPU frequency to Serial

#### Scenario: Maintain timing accuracy at reduced frequency
- **WHEN** operating at 80MHz CPU frequency
- **THEN** all timing operations (millis(), micros(), delays) SHALL remain accurate
- **AND** PWM/LEDC LED control SHALL maintain correct frequencies
- **AND** ESP-NOW communication SHALL function without timing issues
- **AND** button debouncing SHALL work correctly

### Requirement: WiFi Modem Sleep
Each buzzer node SHALL enable WiFi modem sleep to reduce power consumption between ESP-NOW message transmissions and receptions.

#### Scenario: Enable WiFi modem sleep during initialization
- **WHEN** WiFi and ESP-NOW are initialized
- **THEN** the node SHALL call esp_wifi_set_ps(WIFI_PS_MIN_MODEM)
- **AND** WiFi modem SHALL sleep between packets
- **AND** wake automatically for ESP-NOW transmissions
- **AND** wake automatically for ESP-NOW receptions

#### Scenario: Automatic wake for message transmission
- **WHEN** the node needs to send a button press message
- **THEN** WiFi modem SHALL wake automatically
- **AND** transmit the message via ESP-NOW
- **AND** return to modem sleep after transmission completes
- **AND** add no more than 10ms latency to transmission

#### Scenario: Automatic wake for message reception
- **WHEN** the main controller sends a message to the node
- **THEN** WiFi modem SHALL wake to receive the message
- **AND** process the message (LED command, heartbeat, state sync)
- **AND** return to modem sleep after processing
- **AND** maintain reliable message reception

### Requirement: Response Time Guarantee
Each buzzer node SHALL guarantee button press detection and transmission within 50ms to maintain quiz fairness, even with power optimization enabled.

#### Scenario: End-to-end button press latency measurement
- **WHEN** a player presses the buzzer button
- **THEN** the total time from physical press to ESP-NOW transmission SHALL be ≤50ms
- **AND** includes: GPIO wake time (≤5ms) + debounce (50ms max) + processing + transmission
- **AND** this latency SHALL be consistent across all power modes
- **AND** this latency SHALL be equal across all buzzer nodes (±5ms)

#### Scenario: Verify fairness across all nodes
- **WHEN** multiple players press buttons simultaneously
- **THEN** all nodes SHALL have equal wake and processing latency
- **AND** first physical press SHALL always be detected first
- **AND** timing variance between nodes SHALL be ≤5ms
- **AND** power optimization SHALL NOT create unfair timing advantages

### Requirement: Power State Transitions
Each buzzer node SHALL manage transitions between power modes based on game state changes to optimize battery life throughout the quiz session.

#### Scenario: Transition from disconnected to ready
- **WHEN** receiving first heartbeat after disconnection
- **AND** state sync indicates ready state
- **THEN** the node SHALL transition from minimal power mode to active mode
- **AND** enable GPIO wake interrupt for button press
- **AND** reduce sleep duration from 200ms to 50ms
- **AND** complete transition within 100ms

#### Scenario: Transition from ready to locked
- **WHEN** receiving LED command to turn off (locked out)
- **THEN** the node SHALL transition from active mode to low power mode
- **AND** disable GPIO wake interrupt (button inactive)
- **AND** increase sleep duration from 50ms to 100ms
- **AND** maintain heartbeat reception capability

#### Scenario: Transition from locked to ready
- **WHEN** receiving LED command to turn on (reset to ready)
- **THEN** the node SHALL transition from low power mode to active mode
- **AND** re-enable GPIO wake interrupt for button press
- **AND** reduce sleep duration from 100ms to 50ms
- **AND** restore full button responsiveness within 50ms

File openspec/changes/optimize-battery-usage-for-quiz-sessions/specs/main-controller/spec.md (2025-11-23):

## MODIFIED Requirements

### Requirement: Power-On Initialization
Each buzzer node SHALL initialize hardware and communication on power-up, including power management configuration for battery optimization.

#### Scenario: Successful initialization
- **WHEN** the node powers on
- **THEN** it SHALL set CPU frequency to 80MHz for power savings
- **AND** initialize GPIO pins (button input with pullup, LED output)
- **AND** configure button pin as GPIO wake source for light sleep
- **AND** reserve a GPIO pin for future speaker integration (not implemented)
- **AND** initialize PWM/LEDC for LED control
- **AND** set custom MAC address based on NODE_ID
- **AND** initialize WiFi and ESP-NOW with main controller MAC address
- **AND** enable WiFi modem sleep (WIFI_PS_MIN_MODEM)
- **AND** set LED to breathing fade (disconnected state until first heartbeat)
- **AND** print initialization status to Serial at 115200 baud
- **AND** include node ID, custom MAC address, and CPU frequency in output

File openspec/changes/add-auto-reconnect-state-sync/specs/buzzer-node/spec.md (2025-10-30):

## ADDED Requirements

### Requirement: Connection Monitoring
Each buzzer node SHALL monitor its connection to the main controller and detect disconnections.

#### Scenario: Normal heartbeat reception
- **WHEN** the node receives a heartbeat message from the main controller
- **THEN** it SHALL update its last-heartbeat timestamp
- **AND** maintain normal operation with current LED state

#### Scenario: Connection timeout detected
- **WHEN** no heartbeat received for CONNECTION_TIMEOUT_MS (5000ms)
- **THEN** the node SHALL enter disconnected state
- **AND** set LED to rapid blink (5Hz) to indicate error
- **AND** disable button presses
- **AND** log disconnection event to Serial

#### Scenario: Heartbeat received after timeout
- **WHEN** in disconnected state
- **AND** a heartbeat message is received
- **THEN** the node SHALL detect reconnection
- **AND** send MSG_STATE_REQUEST to main controller
- **AND** wait for state sync before updating LED
- **AND** log reconnection event to Serial

### Requirement: State Synchronization
Each buzzer node SHALL request and receive current game state when reconnecting.

#### Scenario: Request state on reconnection
- **WHEN** the node reconnects after timeout
- **THEN** it SHALL send MSG_STATE_REQUEST with its node ID
- **AND** wait up to 1000ms for MSG_STATE_SYNC response
- **AND** retry up to 3 times if no response

#### Scenario: Receive state sync message
- **WHEN** receiving MSG_STATE_SYNC from main controller
- **THEN** the node SHALL extract the LED state for its node ID
- **AND** immediately apply the correct LED state (on/off/blink)
- **AND** restore normal operation
- **AND** log state sync completion to Serial

#### Scenario: State sync timeout
- **WHEN** no MSG_STATE_SYNC received within 1000ms after request
- **THEN** the node SHALL continue rapid LED blink
- **AND** retry MSG_STATE_REQUEST
- **AND** log timeout to Serial

### Requirement: Power Cycle Recovery
Each buzzer node SHALL automatically recover correct state after power cycle.

#### Scenario: Power cycle during ready state
- **WHEN** node powers on
- **AND** main controller is in ready state
- **THEN** the node SHALL connect to main controller
- **AND** receive heartbeat within 5 seconds
- **AND** request state sync
- **AND** restore LED to on (ready state)

#### Scenario: Power cycle during locked state
- **WHEN** node powers on
- **AND** game is in locked state
- **THEN** the node SHALL request and receive current state
- **AND** restore correct LED (off if not selected, blink if selected)
- **AND** maintain proper button disable state

#### Scenario: Power cycle during partial lockout
- **WHEN** node powers on
- **AND** game is in partial lockout state
- **AND** this node is locked out
- **THEN** the node SHALL restore LED to off
- **AND** disable button presses

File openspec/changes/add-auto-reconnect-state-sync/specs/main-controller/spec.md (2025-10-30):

## ADDED Requirements

### Requirement: Heartbeat Broadcasting
The main controller SHALL broadcast periodic heartbeat messages to all buzzer nodes.

#### Scenario: Periodic heartbeat transmission
- **WHEN** the controller is operating
- **THEN** it SHALL broadcast MSG_HEARTBEAT every 2000ms
- **AND** use ESP-NOW broadcast address (FF:FF:FF:FF:FF:FF)
- **AND** include timestamp in heartbeat message

#### Scenario: Heartbeat during all game states
- **WHEN** heartbeat interval expires
- **AND** game is in any state (ready/locked/partial lockout)
- **THEN** the heartbeat SHALL be sent
- **AND** NOT interfere with other message processing

### Requirement: Connection Status Tracking
The main controller SHALL track connection status of each buzzer node.

#### Scenario: Track last-seen timestamp
- **WHEN** receiving any message from a buzzer node
- **THEN** the controller SHALL update that node's last-seen timestamp
- **AND** mark the node as connected if previously disconnected

#### Scenario: Detect node disconnection
- **WHEN** no message received from a node for 5000ms
- **THEN** the controller SHALL mark the node as disconnected
- **AND** log disconnection event to Serial with node ID
- **AND** continue normal operation for other nodes

#### Scenario: Detect node reconnection
- **WHEN** receiving message from previously disconnected node
- **THEN** the controller SHALL mark node as connected
- **AND** log reconnection event to Serial with node ID
- **AND** wait for state sync request

### Requirement: State Synchronization Protocol
The main controller SHALL respond to state sync requests with current game state.

#### Scenario: Receive state sync request
- **WHEN** receiving MSG_STATE_REQUEST from a buzzer node
- **THEN** the controller SHALL determine correct LED state for that node
- **AND** send MSG_STATE_SYNC with current game state
- **AND** include locked buzzer bitmask and selected buzzer ID
- **AND** log state sync event to Serial

#### Scenario: State sync in ready state
- **WHEN** node requests state sync
- **AND** game is in ready state
- **THEN** the controller SHALL send LED_ON for all nodes
- **AND** indicate no buzzers are locked or selected

#### Scenario: State sync in locked state
- **WHEN** node requests state sync
- **AND** game is in locked state
- **THEN** the controller SHALL send LED_BLINK for selected node
- **AND** send LED_OFF for all other nodes
- **AND** include selected buzzer ID in state message

#### Scenario: State sync in partial lockout
- **WHEN** node requests state sync
- **AND** game is in partial lockout state
- **THEN** the controller SHALL send LED_BLINK for selected node
- **AND** send LED_OFF for locked-out nodes
- **AND** send LED_ON for remaining active nodes
- **AND** include locked buzzer bitmask in state message

### Requirement: Reconnection Event Logging
The main controller SHALL log connection status changes via USB Serial.

#### Scenario: Log disconnection event
- **WHEN** a buzzer node disconnects (timeout)
- **THEN** the controller SHALL send "DISCONNECT:<node_id>\n" to serial
- **AND** include timestamp

#### Scenario: Log reconnection event
- **WHEN** a buzzer node reconnects
- **THEN** the controller SHALL send "RECONNECT:<node_id>\n" to serial
- **AND** include timestamp

#### Scenario: Log state sync event
- **WHEN** sending state sync to a reconnected node
- **THEN** the controller SHALL send "STATE_SYNC:<node_id>\n" to serial
- **AND** include current game state in log

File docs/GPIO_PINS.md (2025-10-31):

# Quiz Buzzer System - GPIO Pin Assignments

## Buzzer Node Pins (4 boards)

| Function | GPIO Pin | Mode | Notes |
|---|---|---|---|
| Button Input | 12 | INPUT_PULLUP | Buzzer button, active LOW, white |
| LED Output | 13 | OUTPUT | Status LED (solid/blink/off), red |
| Speaker (reserved) | 14 | Not implemented | Reserved for future audio feedback |

## Main Controller Pins (1 board)

| Function | GPIO Pin | Mode | Notes |
|---|---|---|---|
| Correct Button | 25 | INPUT_PULLUP | Correct answer, active LOW |
| Wrong Button | 26 | INPUT_PULLUP | Wrong answer, active LOW |
| Reset Button | 27 | INPUT_PULLUP | Full reset, active LOW |
| USB Serial | Built-in | - | CH340/CP2102, 115200 baud |

## Hardware Requirements

- 5x Lolin32 Lite boards (ESP32-based)
- 4x Push buttons (for buzzer nodes)
- 3x Push buttons (for main controller)
- 4x LEDs with appropriate resistors (~220Ω for 3.3V)
- 4x 1100mAh 3.7V LiPo batteries (for buzzer nodes)
- 1x USB cable (for main controller → PC connection)
- Breadboards or custom PCB for assembly

## Power Configuration

- **Main Controller**: USB powered (5V from PC)
- **Buzzer Nodes**: Battery powered (1100mAh 3.7V LiPo each)
  - Expected battery life: ~4+ hours with light sleep mode
  - Light sleep mode: ~8mA (vs ~100mA active)
  - Wake on button press via GPIO interrupt

## Notes

- All GPIOs use 3.3V logic levels
- Internal pullups are enabled for all button inputs (no external resistors needed)
- Speaker pins (GPIO 14 on buzzer nodes) are reserved but not used in v1
- Custom MAC addresses are set programmatically, no hardware configuration needed

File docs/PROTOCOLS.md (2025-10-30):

# Communication Protocols

## ESP-NOW Protocol (Buzzer Nodes ↔ Main Controller)

### Custom MAC Addresses

The system uses programmatically-set custom MAC addresses for predictable peer identification:

- **Main Controller**: `AA:BB:CC:DD:EE:00`
- **Buzzer Node 1**: `AA:BB:CC:DD:EE:01`
- **Buzzer Node 2**: `AA:BB:CC:DD:EE:02`
- **Buzzer Node 3**: `AA:BB:CC:DD:EE:03`
- **Buzzer Node 4**: `AA:BB:CC:DD:EE:04`

These are set at startup via `esp_wifi_set_mac()`. No manual MAC address configuration is required.

### Message Structure

```cpp
struct BuzzerMessage {
  uint8_t node_id;      // 1-4 for buzzer nodes, 0 for main controller
  uint8_t msg_type;     // MSG_BUTTON_PRESS, MSG_LED_COMMAND, MSG_ACK, MSG_HEARTBEAT, MSG_STATE_REQUEST, MSG_STATE_SYNC
  uint8_t value;        // LED state, press count, or packed game state
  uint32_t timestamp;   // millis() for deduplication
};
```

### Message Types

| Type | Value | Direction | Description |
|---|---|---|---|
| MSG_BUTTON_PRESS | 1 | Buzzer → Main | Button pressed on buzzer node |
| MSG_LED_COMMAND | 2 | Main → Buzzer | LED control command |
| MSG_ACK | 3 | Bidirectional | Acknowledgment (future use) |
| MSG_HEARTBEAT | 4 | Main → Buzzers | Periodic heartbeat broadcast (every 2s) |
| MSG_STATE_REQUEST | 5 | Buzzer → Main | Request game state after reconnection |
| MSG_STATE_SYNC | 6 | Main → Buzzer | Full game state synchronization |

### LED States

| State | Value | Description |
|---|---|---|
| LED_OFF | 0 | LED off (locked out) |
| LED_ON | 1 | LED solid on (ready/active) |
| LED_BLINK | 2 | LED blinking at 2Hz (selected) or 10Hz (disconnected) |

### Connection Monitoring & Recovery

The system includes automatic connection monitoring and state recovery:

**Heartbeat Mechanism:**
- Main controller broadcasts `MSG_HEARTBEAT` every 2 seconds to all buzzers
- Buzzer nodes track time since last heartbeat received
- If no heartbeat for 5 seconds, buzzer enters "disconnected" state
- Disconnected state indicated by rapid LED blink (10Hz / 100ms interval)

**Reconnection Flow:**
1. Buzzer detects heartbeat after timeout (power cycle or network issue)
2. Buzzer sends `MSG_STATE_REQUEST` to main controller
3. Main controller responds with `MSG_STATE_SYNC` containing current game state
4. Buzzer unpacks state and restores correct LED behavior

**State Sync Message Format (value field):**
- Bits 0-3: `lockedBuzzers` bitmask (bit 0 = buzzer 1, bit 1 = buzzer 2, etc.)
- Bits 4-6: `selectedBuzzer` (0 = none, 1-4 = buzzer ID)
- Bit 7: unused

**Connection Timing Constants:**
- `HEARTBEAT_INTERVAL_MS`: 2000 (2 seconds)
- `CONNECTION_TIMEOUT_MS`: 5000 (5 seconds)
- `RECONNECT_GRACE_PERIOD_MS`: 1000 (1 second after reconnect to process state sync)
- `DISCONNECT_BLINK_INTERVAL_MS`: 100 (rapid blink during disconnection)

**Serial Logging:**
- `DISCONNECT:<node_id>` - Node has timed out
- `RECONNECT:<node_id>` - Node has reconnected
- `STATE_SYNC:<node_id> (state=..., selected=..., locked=...)` - State sync sent

### Message Flow Examples

#### Button Press
1. User presses button on Buzzer Node 2
2. Node 2 sends `BuzzerMessage{node_id=2, msg_type=MSG_BUTTON_PRESS, value=1, timestamp=...}` to main controller
3. Retry up to 3 times with 10ms interval if transmission fails
4. Main controller processes press and updates game state

#### LED Control
1. Main controller determines new LED state for Buzzer Node 3
2. Main sends `BuzzerMessage{node_id=3, msg_type=MSG_LED_COMMAND, value=LED_BLINK, timestamp=...}`
3. Node 3 receives and updates its LED state
4. No acknowledgment required (fire-and-forget)

#### Heartbeat & Connection Monitoring
1. Main controller broadcasts `BuzzerMessage{node_id=0, msg_type=MSG_HEARTBEAT, value=0, timestamp=...}` every 2 seconds
2. All buzzer nodes receive and update their last-heartbeat timestamp
3. If a buzzer doesn't receive heartbeat for 5 seconds, it enters disconnected state (rapid LED blink)
4. Main controller tracks last-seen timestamp for each node; logs `DISCONNECT:<id>` if timeout detected

#### Reconnection & State Sync
1. Buzzer node detects heartbeat after being disconnected (power cycled or network restored)
2. Node sends `BuzzerMessage{node_id=X, msg_type=MSG_STATE_REQUEST, value=0, timestamp=...}`
3. Main controller logs `RECONNECT:<id>` and sends `MSG_STATE_SYNC` with packed game state
4. Node unpacks state (locked bitmask + selected buzzer) and restores correct LED state

### Communication Parameters

- **WiFi Channel**: 1 (configurable in config.h)
- **Encryption**: Disabled (no pairing needed)
- **Typical Latency**: 10-30ms
- **Max Range**: ~50m (line of sight)

---

## USB Serial Protocol (Main Controller → PC)

### Connection Parameters

- **Baud Rate**: 115200
- **Data Bits**: 8
- **Parity**: None
- **Stop Bits**: 1
- **Flow Control**: None

### Message Format

All messages are newline-terminated ASCII text (`\n` = 0x0A).

| Message | Description | Example |
|---|---|---|
| `BUZZER:<id>\n` | Buzzer pressed | `BUZZER:1\n` |
| `CORRECT\n` | Correct answer button pressed | `CORRECT\n` |
| `WRONG\n` | Wrong answer button pressed | `WRONG\n` |
| `RESET\n` | Reset button pressed | `RESET\n` |
| `DISCONNECT:<id>\n` | Buzzer node has disconnected (timeout) | `DISCONNECT:2\n` |
| `RECONNECT:<id>\n` | Buzzer node has reconnected | `RECONNECT:2\n` |
| `STATE_SYNC:<id> (...)\n` | State sync sent to reconnected node (debug) | `STATE_SYNC:2 (state=1, selected=1, locked=0x0)\n` |

### Reading Serial Messages (Python Example)

```python
import serial

ser = serial.Serial('/dev/ttyUSB0', 115200, timeout=1)

while True:
    line = ser.readline().decode('utf-8').strip()
    if line:
        if line.startswith('BUZZER:'):
            buzzer_id = int(line.split(':')[1])
            print(f"Buzzer {buzzer_id} pressed!")
        elif line == 'CORRECT':
            print("Correct answer!")
        elif line == 'WRONG':
            print("Wrong answer!")
        elif line == 'RESET':
            print("System reset!")
```

### Reading Serial Messages (Node.js Example)

```javascript
const SerialPort = require('serialport');
const Readline = require('@serialport/parser-readline');

const port = new SerialPort('/dev/ttyUSB0', { baudRate: 115200 });
const parser = port.pipe(new Readline({ delimiter: '\n' }));

parser.on('data', line => {
  if (line.startsWith('BUZZER:')) {
    const buzzerId = parseInt(line.split(':')[1]);
    console.log(`Buzzer ${buzzerId} pressed!`);
  } else if (line === 'CORRECT') {
    console.log('Correct answer!');
  } else if (line === 'WRONG') {
    console.log('Wrong answer!');
  } else if (line === 'RESET') {
    console.log('System reset!');
  }
});
```

### Message Queue

The main controller maintains a queue of up to 10 messages to handle rapid events without loss. Messages are sent in FIFO order during each loop iteration.

### Debug Output

Additional debug messages may appear on the serial port (e.g., "Buzzer node ready!", "ERROR: ..."). Quiz software should filter these by looking for the defined message patterns.

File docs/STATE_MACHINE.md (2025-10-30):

# Game State Machine

## States

The main controller manages the following game states:

### STATE_READY
**Description**: System is ready for button presses from any buzzer.

**Behavior**:
- All active buzzers have their LEDs **ON** (solid)
- Locked-out buzzers have their LEDs **OFF**
- First button press transitions to STATE_LOCKED
- No buzzer is currently selected

**LED Pattern**: All active = solid ON, locked = OFF

**Transitions**:
- Button press → STATE_LOCKED (set selectedBuzzer)
- Already in ready → stay in STATE_READY

---

### STATE_LOCKED
**Description**: One buzzer has been pressed, all others are locked out.

**Behavior**:
- Selected buzzer LED is **BLINKING** at 2Hz (500ms on/off)
- All other buzzer LEDs are **OFF**
- No additional button presses are accepted
- Game host must press CORRECT or WRONG button

**LED Pattern**: Selected = blink, others = OFF

**Transitions**:
- CORRECT button → STATE_READY (clear selection and lockouts)
- WRONG button → STATE_PARTIAL_LOCKOUT (lock current buzzer)

---

### STATE_PARTIAL_LOCKOUT
**Description**: One or more buzzers gave wrong answers and are locked out. Remaining buzzers can still try.

**Behavior**:
- Previously selected buzzer is added to locked-out list
- LEDs update: locked buzzers **OFF**, active buzzers **ON**
- Next button press from non-locked buzzer → STATE_LOCKED
- If all buzzers become locked out → auto-reset to STATE_READY

**LED Pattern**: Locked = OFF, active = solid ON

**Transitions**:
- Button press from active buzzer → STATE_LOCKED
- All buzzers locked → STATE_READY (auto-reset)
- CORRECT button → STATE_READY (clear all)
- RESET button → STATE_READY (clear all)

---

## State Transitions

```
         ┌──────────────┐
    ┌───►│ STATE_READY  │◄────┐
    │    │ (All LEDs ON)│     │
    │    └──────┬───────┘     │
    │           │              │
    │      Button Press        │
    │           │              │
    │           ▼              │
    │    ┌──────────────┐     │
    │    │STATE_LOCKED  │     │
    │    │(Selected     │     │
    │    │ Blinks)      │     │
    │    └──────┬───────┘     │
    │           │              │
    │    ┌──────┴────────┐    │
    │    │               │    │
    │  WRONG          CORRECT │
    │    │               │    │
    │    ▼               └────┘
    │ ┌──────────────────┐
    │ │STATE_PARTIAL_    │
    │ │  LOCKOUT         │
    │ │(Wrong buzzer OFF,│
    │ │ others ON)       │
    │ └──────┬───────────┘
    │        │
    │   Button Press
    │   (active buzzer)
    │        │
    └────────┘
```

## State Variables

| Variable | Type | Description |
|---|---|---|
| `currentState` | `GameState` | Current state (READY/LOCKED/PARTIAL_LOCKOUT) |
| `selectedBuzzer` | `uint8_t` | Currently selected buzzer (1-4), or 0 if none |
| `lockedBuzzers` | `uint8_t` | Bitmask of locked buzzers (bit 0-3 for buzzers 1-4) |
| `lastPressTime` | `uint32_t` | Timestamp of last press (for tie-breaking) |
| `nodeLastSeen[]` | `unsigned long[4]` | Timestamp of last message from each node |
| `nodeConnected[]` | `bool[4]` | Connection status for each node |

## Connection Monitoring & State Recovery

The system includes automatic connection monitoring to handle buzzer node disconnections (power cycles, network issues, etc.):

### Heartbeat System
- Main controller broadcasts heartbeat every **2 seconds**
- Buzzer nodes track time since last heartbeat
- Timeout after **5 seconds** without heartbeat
- Disconnected buzzers show **rapid LED blink** (10Hz / 100ms interval)

### Reconnection Flow
When a buzzer node reconnects (after timeout or power cycle):

1. **Detection**: Node receives heartbeat after being disconnected
2. **State Request**: Node sends `MSG_STATE_REQUEST` to main controller
3. **State Sync**: Main controller sends `MSG_STATE_SYNC` with packed game state:
   - Bits 0-3: `lockedBuzzers` bitmask
   - Bits 4-6: `selectedBuzzer` (0 = none, 1-4 = buzzer ID)
4. **LED Restoration**: Node unpacks state and restores correct LED behavior:
   - If node is selected → LED_BLINK (2Hz)
   - If node is locked → LED_OFF
   - Otherwise → LED_ON (ready)

### State Preservation During Disconnection
- Main controller maintains game state regardless of node connectivity
- Locked buzzers remain locked even if they disconnect/reconnect
- Selected buzzer status is preserved
- When reconnecting, nodes synchronize to current game state

### Connection Status Tracking
- Main controller tracks last-seen timestamp for each node
- `DISCONNECT:<id>` logged when 5s timeout detected
- `RECONNECT:<id>` logged when node sends any message after timeout
- Connection status does not affect game state logic

## Bitmask Operations

The `lockedBuzzers` variable uses a bitmask to track which buzzers are locked:

```cpp
// Check if buzzer 2 is locked
if (lockedBuzzers & (1 << (2 - 1))) {
  // Buzzer 2 is locked
}

// Lock buzzer 3
lockedBuzzers |= (1 << (3 - 1));

// Clear all locks
lockedBuzzers = 0;

// Check if all buzzers locked (bits 0-3 all set)
if (lockedBuzzers == 0x0F) {
  // All 4 buzzers locked
}
```

## Control Actions

| Action | Button | Behavior |
|---|---|---|
| **Correct Answer** | CTRL_BUTTON_CORRECT (GPIO 25) | Reset to STATE_READY, clear all locks and selection |
| **Wrong Answer** | CTRL_BUTTON_WRONG (GPIO 26) | Lock out selected buzzer, move to PARTIAL_LOCKOUT |
| **Full Reset** | CTRL_BUTTON_RESET (GPIO 27) | Force reset to STATE_READY from any state |

## Example Scenarios

### Scenario 1: Simple Correct Answer
1. Start in STATE_READY (all LEDs on)
2. Buzzer 2 presses → STATE_LOCKED (buzzer 2 blinks, others off)
3. Host presses CORRECT → STATE_READY (all LEDs on)

### Scenario 2: Wrong Answer, Then Correct
1. Start in STATE_READY
2. Buzzer 1 presses → STATE_LOCKED (buzzer 1 blinks)
3. Host presses WRONG → STATE_PARTIAL_LOCKOUT (buzzer 1 off, 2/3/4 on)
4. Buzzer 3 presses → STATE_LOCKED (buzzer 3 blinks, 1 stays off, 2/4 off)
5. Host presses CORRECT → STATE_READY (all LEDs on, locks cleared)

### Scenario 3: Multiple Wrong Answers
1. Start in STATE_READY
2. Buzzer 1 presses → STATE_LOCKED
3. WRONG → STATE_PARTIAL_LOCKOUT (1 locked)
4. Buzzer 2 presses → STATE_LOCKED
5. WRONG → STATE_PARTIAL_LOCKOUT (1,2 locked)
6. Buzzer 3 presses → STATE_LOCKED
7. WRONG → STATE_PARTIAL_LOCKOUT (1,2,3 locked)
8. Buzzer 4 presses → STATE_LOCKED (last buzzer)
9. WRONG → Auto-reset to STATE_READY (all buzzers locked, clear everything)

### Scenario 4: Emergency Reset
1. Any state
2. Host presses RESET → STATE_READY (force clear all state)

### Scenario 5: Buzzer Reconnection During Game
1. Start in STATE_READY (all LEDs on)
2. Buzzer 1 presses → STATE_LOCKED (buzzer 1 blinks)
3. Host presses WRONG → STATE_PARTIAL_LOCKOUT (buzzer 1 locked/off, 2/3/4 on)
4. Buzzer 2 power cycled (unplugged)
   - Main controller detects timeout after 5s → logs `DISCONNECT:2`
   - Buzzer 2 LED enters rapid blink (10Hz) during disconnection
   - Game state preserved: buzzer 1 still locked
5. Buzzer 2 powered back on
   - Receives heartbeat from controller
   - Sends `MSG_STATE_REQUEST`
   - Controller logs `RECONNECT:2`
   - Receives `MSG_STATE_SYNC` with: `lockedBuzzers=0x01` (bit 0 set), `selectedBuzzer=0`
   - LED restores to solid ON (ready state, since not locked or selected)
6. Buzzer 2 can now press button normally
7. Game continues as before reconnection

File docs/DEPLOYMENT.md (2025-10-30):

# Deployment Guide

## Hardware Setup

### Components Needed
- 5x Lolin32 Lite boards (ESP32)
- 7x Push buttons (4 for buzzers, 3 for control)
- 4x LEDs (any color)
- 4x Resistors (220Ω for LEDs)
- 4x 1100mAh 3.7V LiPo batteries (for buzzer nodes)
- 1x USB cable (for main controller)
- Breadboards or custom PCB
- Jumper wires

### Wiring

#### Buzzer Nodes (4 boards)
```
ESP32 Pin 12 → Button → GND (internal pullup enabled)
ESP32 Pin 13 → LED → 220Ω Resistor → GND
ESP32 3.3V   → [future speaker connection]
ESP32 GND    → Common ground
Battery +    → ESP32 VIN or USB
Battery -    → ESP32 GND
```

#### Main Controller (1 board)
```
ESP32 Pin 25 → Correct Button → GND (internal pullup)
ESP32 Pin 26 → Wrong Button → GND (internal pullup)
ESP32 Pin 27 → Reset Button → GND (internal pullup)
ESP32 USB    → PC USB port
```

## Software Flashing

### Prerequisites
1. Install [PlatformIO](https://platformio.org/install) (or use PlatformIO IDE extension for VS Code)
2. Install USB drivers for Lolin32 Lite (CH340 or CP2102)
3. Clone this repository

### Build and Flash Commands

#### Flash Main Controller
```bash
# Connect main controller board via USB
pio run -e main_controller -t upload

# Monitor serial output (optional)
pio device monitor -e main_controller
```

#### Flash Buzzer Nodes (one at a time)
```bash
# Flash buzzer node 1
pio run -e buzzer_node_1 -t upload

# Flash buzzer node 2
pio run -e buzzer_node_2 -t upload

# Flash buzzer node 3
pio run -e buzzer_node_3 -t upload

# Flash buzzer node 4
pio run -e buzzer_node_4 -t upload
```

### Physical Labeling
After flashing each board, **immediately label it** with a sticker or marker:
- Main controller: **"MAIN"**
- Buzzer nodes: **"Buzzer 1"**, **"Buzzer 2"**, **"Buzzer 3"**, **"Buzzer 4"**

This prevents confusion during deployment.

## Verification

### 1. Check Serial Output (Main Controller)
```bash
pio device monitor -e main_controller
```

Expected output:
```
========================================
MAIN CONTROLLER
========================================
Custom MAC address: AA:BB:CC:DD:EE:00
✓ Custom MAC address set successfully
✓ ESP-NOW initialized
✓ Buzzer 1 added as peer
✓ Buzzer 2 added as peer
✓ Buzzer 3 added as peer
✓ Buzzer 4 added as peer
========================================
Main controller ready!
Initializing all LEDs to ON (READY state)
========================================
```

### 2. Check Serial Output (Buzzer Nodes)
For each buzzer node:
```bash
pio device monitor -e buzzer_node_1  # or 2, 3, 4
```

Expected output:
```
========================================
BUZZER NODE 1
========================================
Custom MAC address: AA:BB:CC:DD:EE:01
✓ Custom MAC address set successfully
✓ ESP-NOW initialized
✓ Main controller added as peer
========================================
Buzzer node ready!
========================================
```

### 3. Test Communication
1. Power up main controller first
2. Power up all buzzer nodes
3. All buzzer LEDs should turn ON (ready state)
4. Press any buzzer button
5. That buzzer's LED should start blinking
6. All other buzzer LEDs should turn OFF
7. Main controller serial should show: `BUZZER:X` (where X is 1-4)

### 4. Test Control Buttons
1. Press CORRECT button → All LEDs turn ON, serial shows `CORRECT`
2. Press buzzer again → That buzzer blinks
3. Press WRONG button → Pressed buzzer OFF, others ON, serial shows `WRONG`
4. Press another buzzer → That buzzer blinks
5. Press RESET button → All LEDs ON, serial shows `RESET`

## PC Integration

### Find Serial Port
**Linux/Mac:**
```bash
ls /dev/tty* | grep USB
# Usually /dev/ttyUSB0 or /dev/cu.usbserial-*
```

**Windows:**
```
Device Manager → Ports (COM & LPT)
# Usually COM3, COM4, etc.
```

### Test with Terminal
**Linux/Mac:**
```bash
screen /dev/ttyUSB0 115200
# Or
cat /dev/ttyUSB0
```

**Windows:**
```
# Use PuTTY or Arduino Serial Monitor
# Set baud rate to 115200
```

### Integrate with Quiz Software
See `PROTOCOLS.md` for Python/Node.js examples.

## Troubleshooting

### Buzzer Node LED Not Responding
- Check ESP-NOW initialization (look for errors in serial output)
- Verify custom MAC addresses are set (should show AA:BB:CC:DD:EE:0X)
- Ensure main controller is powered on first
- Check that buzzer node was added as peer on main controller

### Button Press Not Detected
- Test button with multimeter (should short to GND when pressed)
- Check GPIO pin assignments match hardware wiring
- Verify internal pullup is enabled (default in code)
- Check debounce timing (50ms default)

### Serial Messages Not Appearing
- Verify baud rate is 115200
- Check USB cable and drivers
- Look for serial port permissions (Linux: add user to `dialout` group)
- Ensure main controller is receiving button press events (check local serial output)

### ESP-NOW Communication Failures
- Reduce distance between boards (try < 10m initially)
- Check for WiFi interference (try different channel in config.h)
- Verify all boards have correct custom MAC addresses
- Ensure all boards are using same ESP-NOW channel

### Multiple Definition Errors During Build
- This usually means build_src_filter is not working correctly
- Verify platformio.ini has `-<*>` to exclude all files by default
- Check that only the correct .cpp file is included per environment

## Battery Management (Buzzer Nodes)

### Battery Life
- Expected: 4-6 hours continuous use
- Light sleep mode reduces power consumption to ~8mA
- Active mode (LED on): ~100mA

### Low Battery Indication
Currently not implemented in v1. Consider adding voltage monitoring if needed.

### Charging
- Disconnect battery before charging (or use board with built-in charging circuit)
- Use appropriate LiPo charger (3.7V, 1C = 1.1A max)
- Never leave charging unattended

## Production Deployment Checklist

- [ ] All 5 boards flashed with correct firmware
- [ ] All boards physically labeled (Buzzer 1-4, MAIN)
- [ ] All buzzer nodes tested individually
- [ ] Main controller receives messages from all buzzers
- [ ] Control buttons (CORRECT/WRONG/RESET) tested
- [ ] PC serial communication verified
- [ ] Battery life tested (if using batteries)
- [ ] Backup boards prepared (recommended)
- [ ] Quiz software integration tested
- [ ] Range test performed (ensure adequate signal strength)

## Future Enhancements

### Adding Speakers (v2)
- GPIO 14 is reserved on buzzer nodes
- Consider passive buzzers or small speakers
- Add tone() calls in buzzer_node.cpp on button press and LED state changes
- See future proposal for speaker integration

### Battery Power Optimization
- Current implementation uses light sleep between button presses
- Deep sleep not recommended (loses ESP-NOW connection, slow wake)
- Consider adding low-battery voltage monitoring (ADC pin to battery divider)

### Over-the-Air Updates
- Not currently implemented
- Would require WiFi connection and OTA library
- Consider for future versions if remote deployment needed

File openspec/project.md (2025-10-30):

# Project Context

## Purpose
Quiz buzzer system built for ESP32 microcontroller. Designed to handle multiple buzzer inputs for quiz games, with real-time response detection and feedback.

## Tech Stack
- **Platform**: PlatformIO
- **Framework**: Arduino
- **Hardware**: ESP32 (Lolin32 Lite)
- **Language**: C++
- **Build System**: PlatformIO/SCons
- **Tooling**: clangd, clang-tidy for code analysis

## Project Conventions

### Code Style
- C++ with Arduino framework conventions
- Follow standard Arduino naming (setup(), loop() for entry points)
- Use descriptive variable names for GPIO pins and states
- Keep embedded code simple and efficient (memory-constrained environment)
- Use Serial output for debugging at 9600 baud

### Architecture Patterns
- Standard Arduino architecture with setup() and loop()
- Hardware abstraction for buzzer inputs
- Event-driven input handling for button presses
- State machine patterns for game logic (pending, active, locked states)

### Testing Strategy
- Manual testing on hardware
- Serial output for debugging and monitoring
- Unit testing where applicable for pure logic functions

### Git Workflow
- Standard feature branch workflow
- Descriptive commit messages focusing on "why" not "what"
- Test on hardware before committing functional changes

## Domain Context
- Quiz buzzer system: multiple players compete to press their buzzer first
- First press detection with lockout to prevent subsequent presses
- Visual/audio feedback for the first player
- Reset mechanism to start new questions
- Real-time requirements: must detect and respond to button presses within milliseconds

## Important Constraints
- Limited memory on ESP32 (320KB RAM, 4MB flash on Lolin32 Lite)
- Real-time constraints for buzzer detection (sub-100ms response time)
- Power consumption considerations for embedded system
- GPIO pin limitations
- Serial communication at 9600 baud for debugging

## External Dependencies
- Arduino framework libraries
- ESP32 platform libraries (espressif32)
- Hardware-specific libraries for GPIO, timers, interrupts

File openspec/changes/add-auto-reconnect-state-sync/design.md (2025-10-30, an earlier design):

## Context

The current system lacks connection monitoring between the main controller and buzzer nodes. When a buzzer node loses power or WiFi connectivity, it cannot detect the disconnection or automatically recover when reconnected. This requires manual intervention (reset button) to restore proper operation.

ESP-NOW provides no built-in connection tracking - it's a stateless protocol. We need application-level heartbeat and state sync mechanisms.

## Goals / Non-Goals

**Goals:**
- Automatic detection of disconnected buzzer nodes
- Seamless recovery when nodes reconnect without manual reset
- Preserve game state during individual node failures
- Clear visual feedback (LED) when node is disconnected
- Serial logging of connection events for debugging

**Non-Goals:**
- Handling main controller power cycle (game state still resets)
- Persistent storage of game state (remains volatile)
- Network mesh/multi-hop communication
- Automatic firmware updates on reconnect

## Decisions

### Decision: Heartbeat-Based Connection Monitoring

**What:** Main controller broadcasts heartbeat every 2 seconds. Nodes detect timeout after 5 seconds without heartbeat.

**Why:**
- Simple, proven pattern for stateless protocols
- Low overhead (1 small message every 2 seconds)
- Fast detection (5 second timeout is acceptable for quiz application)
- Broadcast reduces message count vs. unicast to each node

**Alternatives considered:**
- Bidirectional ping/pong: Higher message volume (4x), no benefit for our use case
- TCP-like connection tracking: Over-engineered, ESP-NOW is unreliable by design
- No heartbeat, detect on message failure: Cannot detect silent failures (power loss)

### Decision: Pull-Based State Sync on Reconnect

**What:** When node detects reconnection (heartbeat after timeout), it requests state from controller.

**Why:**
- Node knows when it needs state (reconnection event)
- Controller doesn't waste bandwidth pushing state unnecessarily
- Handles race conditions better (node may receive heartbeat before fully initialized)

**Alternatives considered:**
- Push on reconnect: Controller must detect reconnection, risk of missed sync if node not ready
- Periodic state broadcast: Wastes bandwidth, no benefit during stable operation

### Decision: Single State Sync Message with Full Game State

**What:** MSG_STATE_SYNC includes current game state (selected buzzer, locked bitmask, LED states for all nodes).

**Why:**
- Atomic update prevents inconsistent state
- Simple protocol (one message type)
- Handles all edge cases (lockout, partial lockout, ready)

**Alternatives considered:**
- Per-node LED commands: Multiple messages, race conditions possible
- Stateful protocol: Too complex for simple quiz buzzer

### Decision: Rapid LED Blink for Disconnected State

**What:** When node detects timeout, blink LED at 5Hz (100ms on/off).

**Why:**
- Clear visual distinction from other states (ready=solid, selected=2Hz, locked=off)
- Alerts players that node is malfunctioning
- Fast enough to be noticed immediately

**Alternatives considered:**
- LED off: Confusing, looks like lockout
- Same as ready (solid): No indication of problem

## Timing Analysis

### Message Flow Timeline

**Normal Operation (per 2s):**
```
T+0ms:    Controller broadcasts heartbeat
T+<10ms:  All nodes receive heartbeat, update timestamp
T+2000ms: Next heartbeat
```

**Reconnection Flow:**
```
T+0ms:    Node loses power/connection
T+5000ms: Node detects timeout (no heartbeat)
T+5001ms: Node sets LED to rapid blink, disables button
T+6000ms: Node power restored, boots up
T+6500ms: Node receives heartbeat
T+6501ms: Node sends MSG_STATE_REQUEST
T+6520ms: Controller receives request, sends MSG_STATE_SYNC
T+6540ms: Node receives sync, restores correct LED state
```

**Worst-case detection time:** 5 seconds (timeout threshold)  
**Worst-case recovery time:** ~500ms after reconnect (heartbeat interval + round-trip)

### Memory Impact

**Per-node state on controller:**
- last_seen: 4 bytes (uint32_t)
- connected: 1 byte (bool)
- Total: 5 bytes × 4 nodes = 20 bytes

**New message types:**
- MSG_HEARTBEAT: 12 bytes (BuzzerMessage struct)
- MSG_STATE_REQUEST: 12 bytes
- MSG_STATE_SYNC: 12 bytes (reuse existing value field for bitmask)

**Total overhead:** ~20 bytes RAM, negligible flash

## Risks / Trade-offs

### Risk: Heartbeat packet loss causes false disconnection

**Mitigation:** 5-second timeout allows for 2 missed heartbeats (2s interval). ESP-NOW is reliable within range.

**Fallback:** Manual reset button still available if false disconnection occurs.

### Risk: Multiple nodes reconnecting simultaneously

**Mitigation:** State sync is per-node, controller handles requests independently. No shared state locks needed.

**Testing:** Explicitly test in validation (task 5.5).

### Risk: Race condition - heartbeat arrives before node ready

**Mitigation:** Node always requests state on reconnection. If heartbeat arrives before node ready, node will timeout again and retry.

### Risk: State sync message lost

**Mitigation:** Node retries state request up to 3 times with 1s timeout. After 3 failures, continues rapid blink until manual reset.

## Migration Plan

### Implementation Order
1. Protocol updates (MSG types)
2. Configuration constants
3. Controller heartbeat broadcast (non-breaking, nodes ignore unknown messages)
4. Controller state tracking and sync handler
5. Node heartbeat monitoring and state request
6. Testing and validation

### Backward Compatibility
- Old nodes ignore new message types (no handler registered)
- New controller can coexist with old nodes (heartbeat is broadcast, ignored if not handled)
- **Recommendation:** Update all nodes simultaneously in deployment for consistent behavior

### Rollback
- If issues found, flash previous firmware
- No persistent state changes, immediate rollback possible

## Open Questions

None - design is straightforward application of proven patterns.

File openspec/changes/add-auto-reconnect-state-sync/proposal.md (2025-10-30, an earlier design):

## Why

When a buzzer node temporarily loses power or WiFi connection during gameplay, it currently does not recover automatically. When reconnected, the buzzer's LED state does not match the actual game state (e.g., it shows "ready" when the game is locked). This creates confusion and requires manual reset to restore proper operation.

## What Changes

- Add heartbeat mechanism between main controller and buzzer nodes
- Implement automatic state synchronization on reconnection
- Add connection status tracking on both controller and nodes
- Send full game state to reconnecting buzzers
- Handle edge cases: power cycle during lockout, missed state transitions

## Impact

- Affected specs: buzzer-node, main-controller, game-state
- Affected code:
  - `src/controller.cpp` - Add heartbeat broadcast, track node connectivity, state sync on reconnect
  - `src/buzzer_node.cpp` - Add heartbeat monitoring, request state on reconnect
  - `src/protocol.h` - Add new message types (MSG_HEARTBEAT, MSG_STATE_REQUEST, MSG_STATE_SYNC)
  - `src/config.h` - Add timing constants (heartbeat interval, timeout threshold)

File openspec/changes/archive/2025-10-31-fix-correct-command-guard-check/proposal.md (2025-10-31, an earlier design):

# Change Proposal: fix-correct-command-guard-check

## Why

The `handleWrongAnswer()` function correctly checks if a buzzer is selected before processing the command (displaying "No buzzer selected, ignoring WRONG command" when appropriate). However, `handleCorrectAnswer()` lacks this guard check and will incorrectly reset the game state even when no buzzer is selected. This creates inconsistent behavior between CORRECT and WRONG commands, both from physical buttons and serial commands.

According to the main-controller spec (Requirement: Control Button Interface, Scenario: Control button pressed in invalid state), both correct and wrong buttons SHALL be ignored when no buzzer is currently selected. The serial command processing requirement states that serial commands should execute "identical behavior to physical button press", so this guard check applies to both input methods.

## What Changes

- Add a guard check in `handleCorrectAnswer()` to verify that `selectedBuzzer != 0` before processing
- Display "No buzzer selected, ignoring CORRECT command" message (matching WRONG command behavior)
- Return early without changing game state when no buzzer is selected
- Update main-controller spec to explicitly document this validation requirement for serial commands

## Impact

- **Affected specs**: main-controller
- **Affected code**:
  - `src/controller.cpp` - Add guard check to `handleCorrectAnswer()` function
- **Benefits**:
  - Consistent behavior between CORRECT and WRONG commands
  - Prevents unintended game state resets when no buzzer is active
  - Clearer user feedback via serial messages
  - Aligns implementation with existing spec requirements
- **Risks**: 
  - Very low - purely defensive programming
  - No behavior change for valid use cases (only affects invalid state)
  - PC interface or users may need to handle the new ignore case (though they should already handle it for WRONG)

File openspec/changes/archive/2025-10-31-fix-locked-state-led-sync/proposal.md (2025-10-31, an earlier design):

# Change Proposal: fix-locked-state-led-sync

## Why

When a buzzer node reconnects during STATE_LOCKED (one buzzer pressed, all others locked out), non-selected buzzers incorrectly turn their LED ON. This happens because:

1. In STATE_LOCKED, the main controller doesn't populate the `lockedBuzzers` bitmask (it remains 0)
2. The state sync message only sends `lockedBuzzers` and `selectedBuzzer`
3. The buzzer node logic assumes: if not locked and not selected → LED ON (ready state)
4. But in STATE_LOCKED, ALL non-selected buzzers should be OFF

This works correctly for PARTIAL_LOCKOUT because wrong-answer buzzers ARE added to the `lockedBuzzers` bitmask. The issue is that STATE_LOCKED and PARTIAL_LOCKOUT are semantically different but share the same state sync protocol, which doesn't distinguish between them.

## What Changes

- Use bit 7 of the state sync `value` field to encode game state (currently unused)
  - Bit 7 = 0: STATE_LOCKED or STATE_READY (all non-selected buzzers are locked out)
  - Bit 7 = 1: STATE_PARTIAL_LOCKOUT (only explicit `lockedBuzzers` are locked, others are active)
- Update main controller's `sendStateSync()` to set bit 7 when in PARTIAL_LOCKOUT
- Update buzzer node's state sync handler to check bit 7 and apply correct LED logic:
  - If bit 7 = 0 and selectedBuzzer != 0: Only selected buzzer can have LED on, all others OFF
  - If bit 7 = 1: Use existing logic (selected=BLINK, locked=OFF, others=ON)
  - If selectedBuzzer == 0: All LEDs ON (ready state)

## Impact

- **Affected specs**: main-controller, buzzer-node
- **Affected code**:
  - `src/controller.cpp` - Update `sendStateSync()` to set bit 7 based on `currentState`
  - `src/buzzer_node.cpp` - Update state sync handler to check bit 7 for game state
  - `src/protocol.h` - Update comments to document bit 7 usage
- **Benefits**:
  - Correct LED behavior when non-selected buzzer reconnects during STATE_LOCKED
  - Preserves correct behavior for PARTIAL_LOCKOUT reconnections
  - No breaking changes to existing protocol structure
  - Uses currently unused bit, no protocol version change needed
- **Risks**: 
  - Low - uses reserved bit as intended
  - Backwards compatibility: old buzzer node firmware would ignore bit 7 (existing bug persists)
  - Future firmware updates will fix the issue as nodes are updated

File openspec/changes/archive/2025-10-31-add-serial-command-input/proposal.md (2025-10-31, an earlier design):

# Change Proposal: add-serial-command-input

## Why

Currently, the main controller can only be controlled via physical buttons (CORRECT, WRONG, RESET). This requires manual button presses for game control. Adding serial command input enables remote control from PC software, automation, testing, and integration with quiz applications that need to trigger these actions programmatically.
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

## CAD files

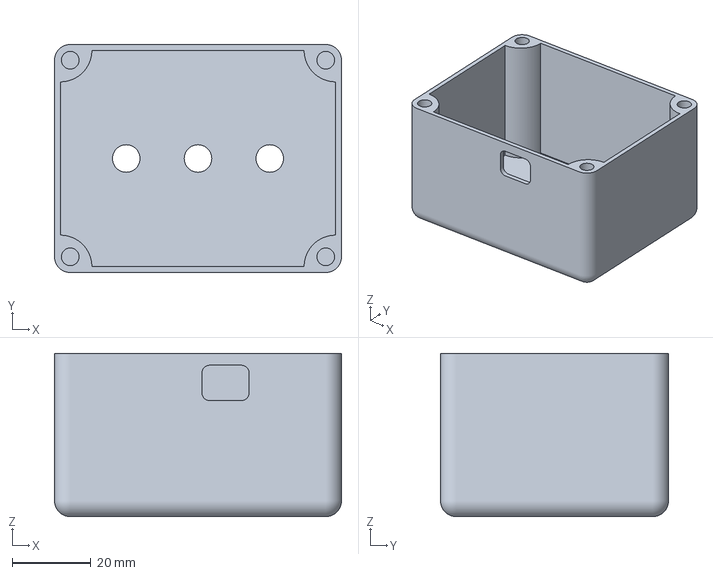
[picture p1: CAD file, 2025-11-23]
case/main_case_2-Case.3mf
73.0 x 58.0 x 41.5 mm

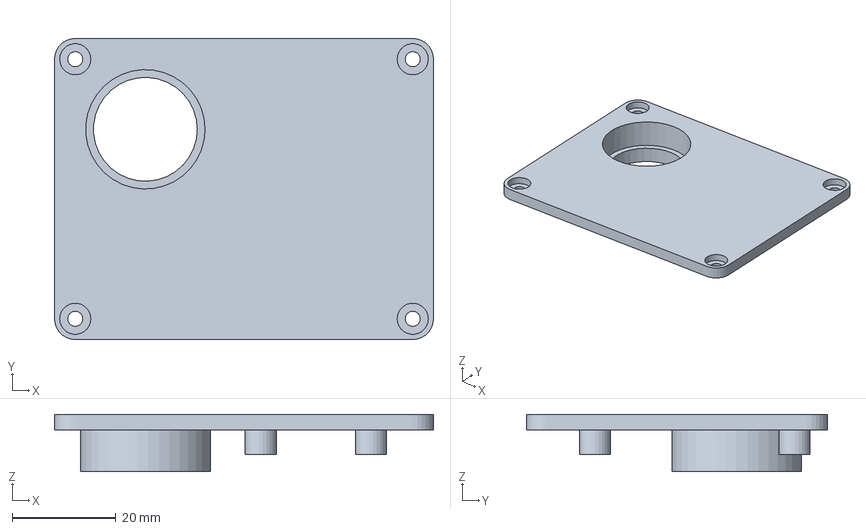
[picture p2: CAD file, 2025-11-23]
case/main_case_2-Lid.3mf
73.0 x 58.0 x 11.0 mm

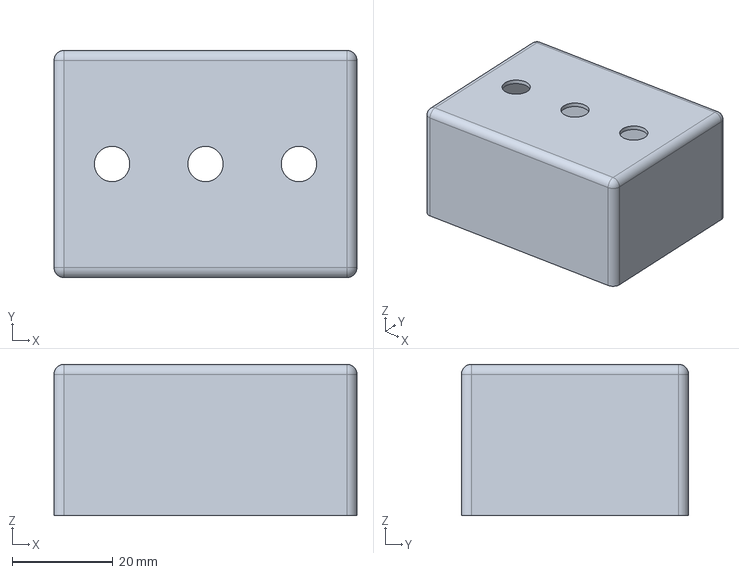
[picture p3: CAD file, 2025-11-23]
case/main_case.FCStd
60.0 x 45.0 x 30.0 mm

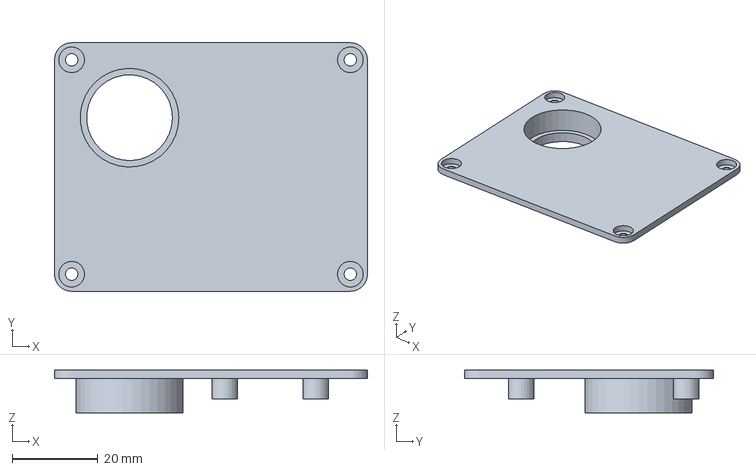
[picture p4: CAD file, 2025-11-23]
case/Unnamed-Lid.3mf
73.0 x 58.0 x 10.0 mm

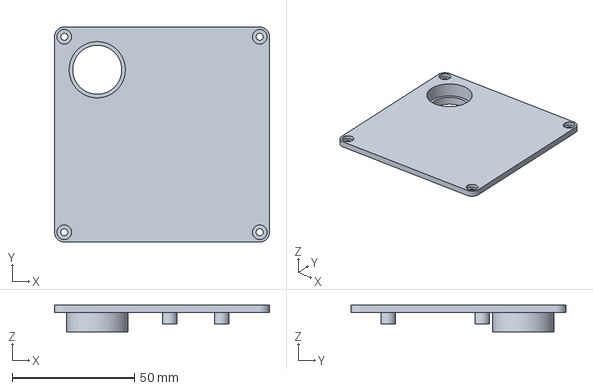
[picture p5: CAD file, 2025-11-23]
case/buzzer_case_2-Lid.3mf
88.0 x 88.0 x 11.0 mm

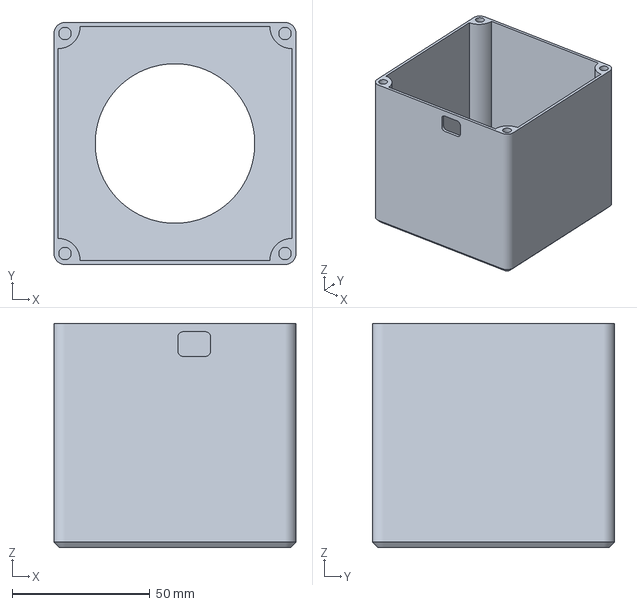
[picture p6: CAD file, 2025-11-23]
case/buzzer_case_2-Case.3mf
88.0 x 88.0 x 81.5 mm

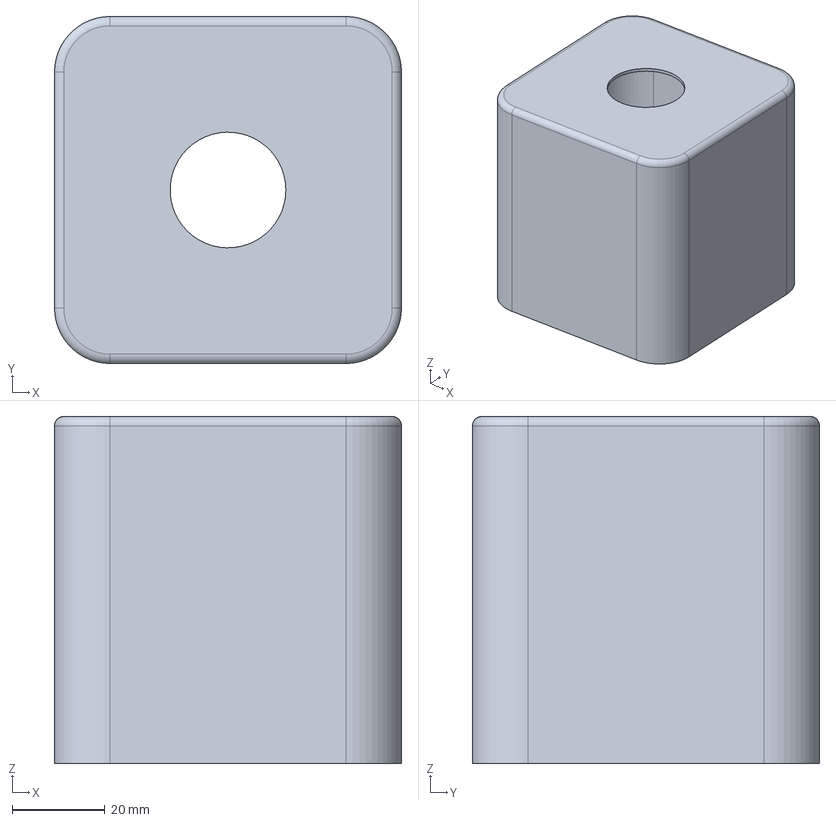
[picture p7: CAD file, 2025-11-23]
case/buzzer_case.FCStd
75.0 x 75.0 x 75.0 mm

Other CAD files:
case/Unnamed-Case.3mf

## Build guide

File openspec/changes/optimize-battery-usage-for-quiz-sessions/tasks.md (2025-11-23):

# Implementation Tasks

## 1. Configuration and Constants
- [x] 1.1 Add power management constants to `src/config.h`
  - Add `#define CPU_FREQUENCY_MHZ 80`
  - Add `#define LIGHT_SLEEP_DURATION_READY_US 50000` (50ms)
  - Add `#define LIGHT_SLEEP_DURATION_LOCKED_US 100000` (100ms)
  - Add `#define LIGHT_SLEEP_DURATION_DISCONNECTED_US 200000` (200ms)
  - Add `#define MAX_BUTTON_RESPONSE_TIME_MS 50`
- [x] 1.2 Add power management includes to `src/buzzer_node.cpp`
  - Add `#include <esp_sleep.h>`
  - Add `#include <esp_pm.h>`

## 2. CPU Frequency Scaling
- [x] 2.1 Implement CPU frequency reduction in buzzer node initialization
  - Call `setCpuFrequencyMhz(CPU_FREQUENCY_MHZ)` in `setup()`
  - Verify frequency with `getCpuFrequencyMhz()` and log to Serial
  - Test that timing functions (millis, micros) remain accurate
- [ ] 2.2 Verify PWM/LEDC operation at 80MHz (HARDWARE TEST REQUIRED)
  - Ensure LED brightness control works correctly
  - Ensure blink timing remains accurate
  - Ensure fade effect remains smooth

## 3. WiFi Modem Sleep
- [x] 3.1 Enable WiFi modem sleep in buzzer node initialization
  - Call `esp_wifi_set_ps(WIFI_PS_MIN_MODEM)` after WiFi.mode(WIFI_STA)
  - Log modem sleep status to Serial
  - Verify ESP-NOW messages still transmit and receive correctly
- [ ] 3.2 Test ESP-NOW latency with modem sleep enabled (HARDWARE TEST REQUIRED)
  - Measure button press to transmission time
  - Verify latency stays under 50ms
  - Test message reception reliability during heartbeat

## 4. Light Sleep with GPIO Wake
- [x] 4.1 Configure GPIO wake source for button pin
  - Call `esp_sleep_enable_gpio_wakeup()` in setup()
  - Configure button pin (BUZZER_BUTTON_PIN) as wake source on LOW level
  - Add RTC_DATA_ATTR variables to preserve state across sleep
- [x] 4.2 Implement light sleep entry/exit logic
  - Create `enterLightSleep(uint64_t duration_us)` function
  - Configure timer wake as backup: `esp_sleep_enable_timer_wakeup(duration_us)`
  - Call `esp_light_sleep_start()` at end of loop()
  - Handle wake cause with `esp_sleep_get_wakeup_cause()`
- [x] 4.3 Track power mode state
  - Add `PowerMode` enum: ACTIVE, LOW_POWER, MINIMAL
  - Add `currentPowerMode` global variable
  - Implement `setPowerMode(PowerMode mode)` function to manage transitions

## 5. Power State Transitions
- [x] 5.1 Implement power mode transitions based on LED state changes
  - Modify `handleLEDCommand()` to call `setPowerMode()` when LED changes
  - LED_ON (ready) → ACTIVE mode (50ms sleep, GPIO wake enabled)
  - LED_OFF (locked) → LOW_POWER mode (100ms sleep, GPIO wake disabled)
  - LED_FADE (disconnected) → MINIMAL mode (200ms sleep, GPIO wake disabled)
- [x] 5.2 Implement dynamic sleep duration selection
  - Modify loop() to select sleep duration based on `currentPowerMode`
  - Pass appropriate duration to `enterLightSleep()`
  - Ensure wake timing matches requirements

## 6. Response Time Verification
- [ ] 6.1 Add latency measurement and logging
  - Record timestamp at button press detection (after wake)
  - Record timestamp at ESP-NOW transmission completion
  - Log total latency to Serial for testing
  - Add warning if latency exceeds 50ms threshold
- [ ] 6.2 Test end-to-end button response time
  - Test with oscilloscope or logic analyzer if available
  - Test button press to LED response time
  - Verify consistent timing across all 4 buzzer nodes
  - Test simultaneous button presses for fairness

## 7. Integration and Testing
- [ ] 7.1 Test power consumption measurement
  - Measure current draw in each power mode (multimeter or power profiler)
  - Document baseline vs optimized power consumption
  - Calculate expected battery life improvement
- [ ] 7.2 Test all game state transitions
  - Test ready → locked → ready cycle
  - Test disconnection and reconnection
  - Test partial lockout scenarios
  - Verify power modes transition correctly
- [ ] 7.3 Test quiz session scenarios
  - Run full quiz session simulation (30-60 minutes)
  - Verify battery life meets expectations
  - Verify no timing regressions or fairness issues
  - Test all 4 nodes simultaneously
- [ ] 7.4 Regression testing
  - Verify all existing LED patterns work correctly
  - Verify heartbeat and state sync still function
  - Verify serial command input still works
  - Run through all existing test scenarios

## 8. Documentation
- [x] 8.1 Update serial debug output
  - Log power mode transitions
  - Log CPU frequency at startup
  - Log WiFi modem sleep status
  - Log measured button response times
- [ ] 8.2 Add comments to power management code
  - Document sleep modes and wake sources
  - Explain power mode state machine
  - Document timing constraints and tradeoffs

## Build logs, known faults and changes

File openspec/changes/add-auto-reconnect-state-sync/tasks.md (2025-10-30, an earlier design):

## 1. Protocol Updates
- [x] 1.1 Add MSG_HEARTBEAT message type to protocol.h
- [x] 1.2 Add MSG_STATE_REQUEST message type to protocol.h
- [x] 1.3 Add MSG_STATE_SYNC message type with game state payload to protocol.h
- [x] 1.4 Add connection status tracking structures

## 2. Configuration
- [x] 2.1 Add HEARTBEAT_INTERVAL_MS constant (default: 2000ms)
- [x] 2.2 Add CONNECTION_TIMEOUT_MS constant (default: 5000ms)
- [x] 2.3 Add RECONNECT_GRACE_PERIOD_MS constant (default: 1000ms)
- [x] 2.4 Add DISCONNECT_BLINK_INTERVAL_MS constant (default: 100ms)

## 3. Main Controller Implementation
- [x] 3.1 Add periodic heartbeat broadcast to all buzzers
- [x] 3.2 Add per-node last-seen timestamp tracking
- [x] 3.3 Add connection status monitoring (detect timeouts)
- [x] 3.4 Implement MSG_STATE_REQUEST handler
- [x] 3.5 Implement MSG_STATE_SYNC sender with current game state
- [x] 3.6 Add reconnection detection logic
- [x] 3.7 Update serial output to log connection/disconnection events

## 4. Buzzer Node Implementation
- [x] 4.1 Add heartbeat reception monitoring
- [x] 4.2 Add connection timeout detection
- [x] 4.3 Implement MSG_STATE_REQUEST sender on reconnect
- [x] 4.4 Implement MSG_STATE_SYNC receiver
- [x] 4.5 Add LED error indication for disconnected state (rapid blink)
- [x] 4.6 Restore correct LED state after receiving state sync
- [x] 4.7 Update serial output to log connection status

## 5. Testing & Validation
- [ ] 5.1 Test power cycle of one buzzer during ready state
- [ ] 5.2 Test power cycle during locked state (both selected and non-selected buzzers)
- [ ] 5.3 Test power cycle during partial lockout state
- [ ] 5.4 Test WiFi interference causing temporary disconnection
- [ ] 5.5 Test all buzzers reconnecting simultaneously
- [ ] 5.6 Verify serial output logs connection events properly
- [x] 5.7 Compile all environments and verify memory usage

## 6. Documentation
- [x] 6.1 Update PROTOCOLS.md with new message types
- [x] 6.2 Update STATE_MACHINE.md with reconnection behavior
- [x] 6.3 Add TROUBLESHOOTING.md section for connection issues
- [x] 6.4 Update README.md with reconnection feature description

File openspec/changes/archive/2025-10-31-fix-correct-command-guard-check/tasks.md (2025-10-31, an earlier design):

# Tasks

## Implementation
- [x] Add selectedBuzzer == 0 guard check at start of handleCorrectAnswer() function in src/controller.cpp
- [x] Add Serial.println message "No buzzer selected, ignoring CORRECT command" when guard check triggers
- [x] Add early return when guard check triggers to prevent state changes
- [x] Ensure message format matches existing handleWrongAnswer() guard message

## Validation
- [x] Manual test: Send CORRECT command via serial when no buzzer is selected - verify ignored with message
- [x] Manual test: Send WRONG command via serial when no buzzer is selected - verify ignored with message
- [x] Manual test: Press physical CORRECT button when no buzzer selected - verify ignored
- [x] Manual test: Normal flow - press buzzer, send CORRECT command - verify works correctly
- [x] Verify no CORRECT message sent to PC interface when command is ignored
- [x] Run openspec validate to ensure spec compliance

## Documentation
- [ ] Update main-controller spec via openspec archive process (automatic)

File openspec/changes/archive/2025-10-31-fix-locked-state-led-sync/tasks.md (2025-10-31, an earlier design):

# Implementation Tasks

## Status: ✅ IMPLEMENTED - Awaiting Hardware Testing

## Completed Tasks

### 1. ✅ Update protocol.h documentation
- **File**: `src/protocol.h:29-31`
- **Change**: Added documentation for bit 7 usage in MSG_STATE_SYNC value field
- **Details**: Documents bit layout for state sync messages

### 2. ✅ Modify sendStateSync() in controller.cpp
- **File**: `src/controller.cpp:177-179`
- **Change**: Set bit 7 when currentState == STATE_PARTIAL_LOCKOUT
- **Implementation**: `if (currentState == STATE_PARTIAL_LOCKOUT) { msg.value |= 0x80; }`

### 3. ✅ Update state sync handler in buzzer_node.cpp
- **File**: `src/buzzer_node.cpp:93,118-131`
- **Changes**:
  - Extract bit 7 to `isPartialLockout` boolean
  - Replace simple `isLocked` check with conditional logic:
    - If `isPartialLockout` is true: only turn OFF if explicitly in locked bitmask, otherwise ON
    - If `isPartialLockout` is false: all non-selected buzzers turn OFF (STATE_LOCKED behavior)

### 4. ✅ Build verification
- **Status**: Build successful
- **Details**: All environments compile without errors

## Pending Tasks

### 5. Hardware Testing
- **Status**: AWAITING USER TESTING
- **Test Scenarios**:
  1. Buzzer 1 presses → disconnect Buzzer 2 → reconnect Buzzer 2
     - Expected: Buzzer 2 LED stays OFF (STATE_LOCKED)
  2. Buzzer 1 presses → WRONG → disconnect Buzzer 1 → reconnect Buzzer 1
     - Expected: Buzzer 1 LED turns OFF (locked in PARTIAL_LOCKOUT)
  3. Buzzer 1 presses → WRONG → disconnect Buzzer 2/3/4 → reconnect them
     - Expected: Buzzer 2/3/4 LEDs turn ON (not locked in PARTIAL_LOCKOUT)

## Change Summary

**Problem**: Non-selected buzzers incorrectly turned ON when reconnecting during STATE_LOCKED.

**Solution**: Use bit 7 of state sync value field to distinguish between STATE_LOCKED (all non-selected OFF) and STATE_PARTIAL_LOCKOUT (only locked bitmask OFF).

**Files Modified**:
- `src/protocol.h` - Documentation update
- `src/controller.cpp` - Set bit 7 for PARTIAL_LOCKOUT
- `src/buzzer_node.cpp` - Check bit 7 and apply correct LED logic

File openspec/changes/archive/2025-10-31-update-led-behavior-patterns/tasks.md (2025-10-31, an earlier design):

# Tasks: update-led-behavior-patterns

## Implementation Tasks

- [x] **Task 1.1**: Add PWM/LEDC configuration constants to config.h
  - Add LED PWM channel number (0-15)
  - Add PWM frequency (5000 Hz recommended)
  - Add PWM resolution (8-bit = 0-255)
  - Add fade step increment and timing constants
  - Add fast-blink duration constant (3000ms)
  - Add fast-blink interval constant (100ms for 5Hz)

- [x] **Task 1.2**: Add new LED state enum and variables
  - Add LED_FADE state to LEDState enum in protocol.h
  - Add LED_BLINK_FAST sub-state for pressed buzzer
  - Add fade-related variables (brightness, fadeDirection, fadeStep)
  - Add blink-phase variables (fastBlinkStartTime, isInFastBlinkPhase)

- [x] **Task 1.3**: Initialize PWM/LEDC in setup()
  - Call ledcSetup() with channel, frequency, and resolution
  - Call ledcAttachPin() to attach LED pin to PWM channel
  - Replace digitalWrite() calls with ledcWrite() for PWM control
  - Test PWM initialization and verify LED responds to brightness changes

- [x] **Task 1.4**: Implement smooth breathing fade logic
  - Create handleLEDFade() function for smooth brightness transitions
  - Implement fade-in from 0 to 255 brightness
  - Implement fade-out from 255 to 0 brightness
  - Use smooth sine or linear interpolation for natural breathing effect
  - Call during disconnected state only

- [x] **Task 1.5**: Implement two-stage blink pattern for pressed state
  - Detect when transitioning to LED_BLINK state (pressed acknowledged)
  - Start 3-second fast-blink phase at 5Hz (100ms on/off)
  - Track elapsed time from fast-blink start
  - After 3 seconds, transition to normal 2Hz blink (500ms on/off)
  - Ensure smooth transition between phases

- [x] **Task 1.6**: Update handleLED() function
  - Add case for LED_FADE state (call handleLEDFade)
  - Update LED_BLINK case to support two-stage pattern
  - Keep LED_ON as full brightness PWM (255)
  - Keep LED_OFF as zero brightness PWM (0)
  - Remove old digitalWrite() calls, use ledcWrite() throughout

- [x] **Task 1.7**: Update connection state transitions
  - Set LED to LED_FADE when entering disconnected state
  - Set LED to LED_ON (solid) when connection established
  - Ensure fade stops and LED transitions to solid on reconnect
  - Test reconnection scenarios

## Testing Tasks

- [ ] **Task 2.1**: Test PWM fade implementation
  - Verify smooth breathing effect during disconnected state
  - Check fade timing and brightness curve smoothness
  - Ensure no visible flicker or stuttering
  - Test on actual hardware (PWM frequency matters)

- [ ] **Task 2.2**: Test two-stage blink pattern
  - Press buzzer and verify 5Hz fast blink starts immediately
  - Verify timing: exactly 3 seconds of fast blink
  - Verify smooth transition to 2Hz normal blink after 3 seconds
  - Test multiple button presses in sequence

- [ ] **Task 2.3**: Test state transitions
  - Disconnect controller and verify breathing fade starts
  - Reconnect and verify fade stops, LED goes solid ON
  - Press buzzer while connected and verify fast→slow blink
  - Reset game and verify LED returns to solid ON

- [ ] **Task 2.4**: Test edge cases
  - Power cycle during fast-blink phase (should resume correct state)
  - Disconnect during fast-blink phase (should switch to breathing)
  - Multiple rapid state changes
  - Verify locked-out state still shows LED OFF

## Documentation Tasks

- [x] **Task 3.1**: Update buzzer-node spec
  - Modify LED Visual Feedback requirement
  - Update disconnected state scenario to describe breathing effect
  - Add two-stage blink pattern scenario for pressed state
  - Document PWM usage and timing constants
  - Update timing specifications (5Hz fast, 2Hz slow, fade parameters)

- [x] **Task 3.2**: Update code comments
  - Document PWM channel configuration
  - Explain fade algorithm and brightness calculation
  - Document two-stage blink state machine
  - Add timing diagrams in comments if helpful

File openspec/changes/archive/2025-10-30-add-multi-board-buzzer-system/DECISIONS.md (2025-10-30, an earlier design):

# Design Decisions Summary

## Hardware Configuration

### Speakers
- **Decision**: Each buzzer node will have a speaker (4 speakers total, not on main controller)
- **Status**: DEFERRED to future proposal
- **Current Action**: Reserve GPIO pin on buzzer nodes for future speaker integration
- **Rationale**: Localized audio feedback per player, but not needed for MVP functionality

### Power Supply
- **Decision**: USB power for all 5 boards
- **Future**: Design allows for battery operation on buzzer nodes later
- **Rationale**: Simpler initial deployment, battery can be added without firmware changes

## Software Configuration

### MAC Addresses
- **Decision**: Custom MAC addresses set programmatically
- **Implementation**: 
  ```cpp
  uint8_t customMAC[6] = {0xAA, 0xBB, 0xCC, 0xDD, 0xEE, NODE_ID};
  esp_wifi_set_mac(WIFI_IF_STA, customMAC);
  ```
- **Benefits**:
  - No need to read and manually configure MAC addresses
  - Main controller can hardcode known addresses
  - Predictable MAC pattern: :01, :02, :03, :04
  - Same firmware can be flashed to any main controller board

### Node ID Configuration
- **Decision**: Build-time configuration via PlatformIO build flags
- **Implementation**: 4 separate build environments (buzzer_node_1 through buzzer_node_4)
- **Example**: 
  ```ini
  [env:buzzer_node_1]
  build_flags = -DNODE_ID=1
  
  [env:buzzer_node_2]
  build_flags = -DNODE_ID=2
  ```
- **Deployment**: 
  - Flash with: `pio run -e buzzer_node_1 -t upload`
  - Label board physically: "Buzzer 1"

### LED Blink Rate
- **Decision**: 2Hz (500ms on, 500ms off) for selected buzzer
- **Implementation**: `#define BLINK_INTERVAL_MS 500` in config.h
- **Rationale**: Easy to tune based on user feedback

## GPIO Pin Allocation

### Buzzer Node Pins
- Button input: TBD (with internal pullup)
- LED output: TBD
- Speaker (reserved): TBD (not implemented in v1)

### Main Controller Pins
- Control button 1 (correct): TBD (with internal pullup)
- Control button 2 (wrong): TBD (with internal pullup)
- Control button 3 (reset): TBD (with internal pullup)
- USB serial: Built-in (CH340/CP2102)

## Communication Protocols

### ESP-NOW (Buzzer Nodes ↔ Main Controller)
- **Custom MAC addresses**: AA:BB:CC:DD:EE:01 through :04
- **Message format**: Binary struct with node_id, msg_type, value, timestamp
- **Retry logic**: Up to 3 retries with 10ms interval for button presses
- **Latency**: 10-30ms typical

### USB Serial (Main Controller ↔ PC)
- **Baud rate**: 115200
- **Message format**: Newline-terminated ASCII text
- **Protocol**: 
  - `BUZZER:1\n` through `BUZZER:4\n`
  - `CORRECT\n`, `WRONG\n`, `RESET\n`
  - `DEBUG: <message>\n`
- **Latency**: <100ms from button press to PC

## Deployment Process

1. Flash buzzer nodes (4 boards):
   ```bash
   pio run -e buzzer_node_1 -t upload
   pio run -e buzzer_node_2 -t upload
   pio run -e buzzer_node_3 -t upload
   pio run -e buzzer_node_4 -t upload
   ```

2. Label each board physically: "Buzzer 1" through "Buzzer 4"

3. Flash main controller (1 board):
   ```bash
   pio run -e main_controller -t upload
   ```

4. Label main board: "MAIN"

5. Power up and verify custom MAC addresses in serial output

6. Connect main board to PC and test with quiz software

## Future Enhancements (Out of Scope for v1)

- [ ] Speaker audio feedback on buzzer nodes
- [ ] Battery operation for wireless buzzer nodes
- [ ] DIP switch configuration for node IDs
- [ ] Auto-discovery of buzzer nodes
- [ ] Over-the-air (OTA) firmware updates
- [ ] Visual display screen integration
- [ ] Built-in score tracking

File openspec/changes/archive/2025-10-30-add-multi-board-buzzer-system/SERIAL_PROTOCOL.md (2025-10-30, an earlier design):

# USB Serial Protocol

## Connection Settings
- **Baud Rate**: 115200
- **Data Bits**: 8
- **Parity**: None
- **Stop Bits**: 1
- **Flow Control**: None

## Message Format
All messages are newline-terminated ASCII text strings (`\n`).

## Protocol Messages

### Buzzer Press Events
```
BUZZER:1\n    # Player 1 buzzed in
BUZZER:2\n    # Player 2 buzzed in
BUZZER:3\n    # Player 3 buzzed in
BUZZER:4\n    # Player 4 buzzed in
```

### Control Button Events
```
CORRECT\n     # Correct answer button pressed
WRONG\n       # Wrong answer button pressed
RESET\n       # Reset button pressed
```

## Debug Messages
Debug messages are prefixed with `DEBUG: ` and can be filtered out by quiz software:
```
DEBUG: System initialized\n
DEBUG: ESP-NOW ready\n
DEBUG: ERROR: Communication timeout\n
```

## Example Session
```
DEBUG: Quiz Buzzer System v1.0\n
DEBUG: Initializing ESP-NOW...\n
DEBUG: ESP-NOW ready\n
DEBUG: Ready for input\n
BUZZER:3\n
WRONG\n
BUZZER:1\n
CORRECT\n
RESET\n
```

## PC Software Integration

### Python Example
```python
import serial

ser = serial.Serial('/dev/ttyUSB0', 115200)

while True:
    line = ser.readline().decode('utf-8').strip()
    
    if line.startswith('DEBUG:'):
        print(f"[DEBUG] {line[7:]}")  # Optional: log debug info
        continue
    
    if line.startswith('BUZZER:'):
        buzzer_id = int(line.split(':')[1])
        print(f"Player {buzzer_id} buzzed in!")
    elif line == 'CORRECT':
        print("Correct answer!")
    elif line == 'WRONG':
        print("Wrong answer!")
    elif line == 'RESET':
        print("Game reset!")
```

### Node.js Example
```javascript
const SerialPort = require('serialport');
const Readline = require('@serialport/parser-readline');

const port = new SerialPort('COM3', { baudRate: 115200 });
const parser = port.pipe(new Readline({ delimiter: '\n' }));

parser.on('data', (line) => {
  if (line.startsWith('DEBUG:')) {
    console.log(`[DEBUG] ${line.substring(7)}`);
    return;
  }
  
  if (line.startsWith('BUZZER:')) {
    const buzzerId = parseInt(line.split(':')[1]);
    console.log(`Player ${buzzerId} buzzed in!`);
  } else if (line === 'CORRECT') {
    console.log('Correct answer!');
  } else if (line === 'WRONG') {
    console.log('Wrong answer!');
  } else if (line === 'RESET') {
    console.log('Game reset!');
  }
});
```

## Message Timing
- Messages sent within **50ms** of event occurrence
- Messages arrive at PC within **100ms** of button press
- Queue holds up to **10 messages** during bursts
- Oldest messages discarded if queue overflows

## Error Handling
- System continues operating if USB disconnected
- Messages queued (up to 10) and sent when reconnected
- Debug messages indicate errors and status changes

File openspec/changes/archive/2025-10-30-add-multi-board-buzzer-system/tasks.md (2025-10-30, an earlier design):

## 1. Project Structure Setup
- [x] 1.1 Create separate source files for buzzer node and main controller
- [x] 1.2 Add platformio environments for different board roles (buzzer_node_1-4, main_controller)
- [x] 1.3 Define common protocol header file for ESP-NOW messages
- [x] 1.4 Set up conditional compilation for buzzer vs controller roles
- [x] 1.5 Add build flags for NODE_ID (1-4) per buzzer environment
- [x] 1.6 Create config.h for pin assignments and constants (LED blink rate, custom MAC base)

## 2. Buzzer Node Implementation
- [x] 2.1 Configure GPIO pins (button input with pullup, LED output)
- [x] 2.2 Set custom MAC address based on NODE_ID using esp_wifi_set_mac()
- [x] 2.3 Implement button debouncing and press detection
- [x] 2.4 Set up ESP-NOW communication with main controller
- [x] 2.5 Implement button press message transmission with retry logic
- [x] 2.6 Implement LED control based on received commands (on/off/blink)
- [x] 2.7 Add serial output showing node ID and custom MAC address
- [x] 2.8 Reserve GPIO pin for future speaker integration (document in comments)
- [x] 2.9 Test individual buzzer node functionality

## 3. Main Controller - Communication Layer
- [x] 3.1 Initialize ESP-NOW as receiver for 4 buzzer nodes
- [x] 3.2 Hardcode custom MAC addresses of buzzer nodes (AA:BB:CC:DD:EE:01-04)
- [x] 3.3 Implement message reception handler for button presses
- [x] 3.4 Implement broadcast/unicast LED command transmission
- [x] 3.5 Add message acknowledgment and retry logic
- [x] 3.6 Test communication with all 4 nodes

## 4. Main Controller - Game State Machine
- [x] 4.1 Define game states (READY, LOCKED, PARTIAL_LOCKOUT)
- [x] 4.2 Track which buzzers are currently allowed to press
- [x] 4.3 Implement first-press detection and lockout logic
- [x] 4.4 Track currently selected buzzer (for blinking LED)
- [x] 4.5 Implement correct answer handler (reset to READY, all LEDs on)
- [x] 4.6 Implement wrong answer handler (PARTIAL_LOCKOUT, exclude wrong buzzer)
- [x] 4.7 Implement full reset handler (clear all state, return to READY)
- [x] 4.8 Add state transition validation and logging

## 5. Main Controller - Control Interface
- [x] 5.1 Configure 3 GPIO input pins for control buttons with pullups
- [x] 5.2 Implement button debouncing for control inputs
- [x] 5.3 Map button 1 to "correct answer" action
- [x] 5.4 Map button 2 to "wrong answer" action
- [x] 5.5 Map button 3 to "full reset" action
- [x] 5.6 Add visual/serial feedback for control button presses

## 6. PC Interface - USB Serial
- [x] 6.1 Configure serial communication at 115200 baud
- [x] 6.2 Implement text-based message protocol (BUZZER:<id>, CORRECT, WRONG, RESET)
- [x] 6.3 Send buzzer press messages to serial port
- [x] 6.4 Send control button messages to serial port
- [x] 6.5 Add message queuing for rapid events (max 10 messages)
- [x] 6.6 Implement newline-terminated message framing
- [x] 6.7 Test PC serial port reception and parsing

## 7. Integration and Testing
- [x] 7.1 Test full workflow: ready → buzzer press → lock → correct answer → reset
- [x] 7.2 Test wrong answer workflow: ready → press → wrong → press again → correct
- [x] 7.3 Test multiple wrong answers in sequence with selective lockout
- [x] 7.4 Test full reset from any state
- [x] 7.5 Verify LED feedback on all 4 nodes for each state
- [x] 7.6 Test ESP-NOW reliability and message timing
- [x] 7.7 Verify PC receives correct serial messages for all events
- [x] 7.8 Load test with rapid button presses

## 8. Documentation and Future Prep
- [x] 8.1 Document GPIO pin assignments for all boards
- [x] 8.2 Document ESP-NOW message protocol and serial message format
- [x] 8.3 Document game state machine transitions
- [x] 8.4 Document custom MAC address scheme (AA:BB:CC:DD:EE:01-04)
- [x] 8.5 Add comments marking GPIO pins reserved for future speaker integration
- [x] 8.6 Create flashing instructions for each board type with build environment names
- [x] 8.7 Add troubleshooting guide for common issues
- [x] 8.8 Document speaker feature as future enhancement (out of scope for v1)

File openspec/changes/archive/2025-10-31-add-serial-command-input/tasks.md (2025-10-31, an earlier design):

# Tasks: add-serial-command-input

## Implementation Tasks

- [x] **Task 1.1**: Add serial input buffer and parsing function in controller.cpp
  - Add string buffer to accumulate incoming characters until newline
  - Implement `handleSerialInput()` function to read Serial.available() and parse commands
  - Handle line-based protocol (newline-terminated commands)

- [x] **Task 1.2**: Implement command parsing logic
  - Parse "CORRECT\n" and call `handleCorrectAnswer()`
  - Parse "WRONG\n" and call `handleWrongAnswer()`
  - Parse "RESET\n" and call `handleFullReset()`
  - Ignore unknown commands with optional debug warning

- [x] **Task 1.3**: Integrate serial input handler into main loop
  - Call `handleSerialInput()` in `loop()` after `processMessageQueue()`
  - Ensure non-blocking operation (only process available bytes)
  - Test that serial input and button input work simultaneously

- [x] **Task 1.4**: Add command echo/acknowledgment (optional)
  - When command is received, optionally echo "CMD:<command>\n" for confirmation
  - Helps with debugging and PC software integration

## Testing Tasks

- [x] **Task 2.1**: Unit test command parsing
  - Test each command string (CORRECT, WRONG, RESET)
  - Test partial commands and buffer handling
  - Test commands with different line endings (\n, \r\n)

- [x] **Task 2.2**: Integration test with hardware
  - Send commands via serial terminal while game is running
  - Verify game state changes correctly (same as button presses)
  - Test concurrent button press and serial command
  - Verify serial output messages still work correctly

- [x] **Task 2.3**: Test invalid input handling
  - Send unknown commands and verify they're ignored
  - Send malformed input and verify no crashes
  - Test very long lines (buffer overflow protection)

## Documentation Tasks

- [x] **Task 3.1**: Update pc-interface spec
  - Add requirement for bidirectional serial communication
  - Document inbound command format (CORRECT\n, WRONG\n, RESET\n)
  - Add scenarios for command reception and handling

- [x] **Task 3.2**: Update main-controller spec
  - Add requirement for serial command processing
  - Document command parsing and execution
  - Add scenarios for command handling in different game states

- [x] **Task 3.3**: Update README
  - Add section on serial command interface
  - Provide examples of sending commands from PC
  - Document command format and expected behavior

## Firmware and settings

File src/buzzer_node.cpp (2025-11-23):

#include "config.h"
#include "protocol.h"
#include <Arduino.h>
#include <WiFi.h>
#include <esp_now.h>
#include <esp_wifi.h>
#include <esp_sleep.h>
#include <esp_pm.h>

// Ensure NODE_ID is defined at compile time
#ifndef NODE_ID
#error "NODE_ID must be defined (1-4) via build flags"
#endif

#if NODE_ID < 1 || NODE_ID > 4
#error "NODE_ID must be between 1 and 4"
#endif

// ============================================================================
// GLOBAL STATE
// ============================================================================

// Power mode management for battery optimization
enum PowerMode {
  ACTIVE,      // Ready state: 50ms sleep, GPIO wake enabled, fast button response
  LOW_POWER,   // Locked state: 100ms sleep, GPIO wake disabled, button inactive
  MINIMAL      // Disconnected state: 200ms sleep, GPIO wake disabled, breathing LED
};

PowerMode currentPowerMode = MINIMAL; // Start in minimal power mode (disconnected)

// LED state management
LEDState currentLEDState = LED_OFF;
LEDState savedLEDState = LED_OFF; // Save state before disconnection
unsigned long lastBlinkTime = 0;
bool blinkState = false;

// LED fade variables for breathing effect
// Breathing fade is used during disconnected state for smooth visual feedback
uint8_t fadeBrightness = 0;        // Current brightness (0-255)
int8_t fadeDirection = 1;          // 1 for fade-in, -1 for fade-out
unsigned long lastFadeTime = 0;    // Last time fade was updated

// Two-stage blink variables for pressed state
// Fast blink (5Hz) for 3 seconds grabs attention, then slow blink (2Hz) continues
unsigned long fastBlinkStartTime = 0;  // When fast blink phase started
bool isInFastBlinkPhase = false;       // True if in 5Hz fast blink phase

// Button state management
bool lastButtonState = HIGH;
unsigned long lastDebounceTime = 0;

// Connection monitoring
unsigned long lastHeartbeatTime = 0;
bool isConnected = false;

// Main controller MAC address (will be set to AA:BB:CC:DD:EE:00)
uint8_t mainControllerMAC[6] = {0xAA, 0xBB, 0xCC, 0xDD, 0xEE, 0x00};

// ============================================================================
// POWER MANAGEMENT
// ============================================================================

// Set power mode and configure sleep parameters accordingly
void setPowerMode(PowerMode mode) {
  if (currentPowerMode == mode) {
    return; // No change needed
  }
  
  PowerMode oldMode = currentPowerMode;
  currentPowerMode = mode;
  
  // Log power mode transition
  Serial.print("Power mode transition: ");
  switch (oldMode) {
    case ACTIVE: Serial.print("ACTIVE"); break;
    case LOW_POWER: Serial.print("LOW_POWER"); break;
    case MINIMAL: Serial.print("MINIMAL"); break;
  }
  Serial.print(" -> ");
  switch (mode) {
    case ACTIVE: Serial.println("ACTIVE"); break;
    case LOW_POWER: Serial.println("LOW_POWER"); break;
    case MINIMAL: Serial.println("MINIMAL"); break;
  }
}

// Enter light sleep with appropriate wake sources
void enterLightSleep(uint64_t duration_us) {
  // Configure timer wake as backup
  esp_sleep_enable_timer_wakeup(duration_us);
  
  // Configure GPIO wake only in ACTIVE mode (button responsive)
  if (currentPowerMode == ACTIVE) {
    // Enable GPIO wake on button press (LOW level due to pullup)
    gpio_wakeup_enable((gpio_num_t)BUZZER_BUTTON_PIN, GPIO_INTR_LOW_LEVEL);
    esp_sleep_enable_gpio_wakeup();
  } else {
    // Disable GPIO wake in low power modes (button inactive)
    esp_sleep_disable_wakeup_source(ESP_SLEEP_WAKEUP_GPIO);
  }
  
  // Enter light sleep (wakes on GPIO interrupt or timer)
  esp_light_sleep_start();
}

// ============================================================================
// ESP-NOW CALLBACKS
// ============================================================================

void onDataReceive(const uint8_t *mac, const uint8_t *data, int len) {
  if (len != sizeof(BuzzerMessage)) {
    Serial.println("ERROR: Received message with wrong size");
    return;
  }

  BuzzerMessage msg;
  memcpy(&msg, data, sizeof(msg));

  // Handle heartbeat messages from controller
  if (msg.msg_type == MSG_HEARTBEAT) {
    unsigned long now = millis();
    bool wasConnected = isConnected;
    lastHeartbeatTime = now;
    
    if (!wasConnected) {
      // We just reconnected
      Serial.println("Connected to controller");
      isConnected = true;
      
      // Request current game state
      BuzzerMessage stateReq;
      stateReq.node_id = NODE_ID;
      stateReq.msg_type = MSG_STATE_REQUEST;
      stateReq.value = 0;
      stateReq.timestamp = now;
      
      Serial.println("Requesting state sync...");
      esp_now_send(mainControllerMAC, (uint8_t *)&stateReq, sizeof(stateReq));
    }
    return;
  }

  // Handle state sync messages
  if (msg.msg_type == MSG_STATE_SYNC && msg.node_id == NODE_ID) {
    Serial.println("=== STATE SYNC RECEIVED ===");
    
    // Unpack game state from value field
    uint8_t lockedBuzzers = msg.value & 0x0F;     // Bits 0-3
    uint8_t selectedBuzzer = (msg.value >> 4) & 0x07; // Bits 4-6
    bool isPartialLockout = (msg.value & 0x80) != 0;  // Bit 7
    
    Serial.print("  Locked buzzers: 0x");
    Serial.print(lockedBuzzers, HEX);
    Serial.print(" | Selected buzzer: ");
    Serial.print(selectedBuzzer);
    Serial.print(" | Mode: ");
    Serial.println(isPartialLockout ? "PARTIAL_LOCKOUT" : "LOCKED");
    
    // Determine correct LED state based on game state
    bool isLocked = lockedBuzzers & (1 << (NODE_ID - 1));
    bool isSelected = (selectedBuzzer == NODE_ID);
    
    Serial.print("  This node: locked=");
    Serial.print(isLocked ? "YES" : "NO");
    Serial.print(" | selected=");
    Serial.println(isSelected ? "YES" : "NO");
    
    if (isSelected) {
      currentLEDState = LED_BLINK;
      lastBlinkTime = millis(); // Reset blink timer to start immediately
      // Start two-stage blink: fast blink for 3 seconds, then slow
      isInFastBlinkPhase = true;
      fastBlinkStartTime = millis();
      Serial.println("  -> LED state: BLINK (selected)");
      setPowerMode(LOW_POWER); // Button locked, use low power mode
    } else if (selectedBuzzer == 0) {
      // STATE_READY: no buzzer selected, all LEDs ON
      currentLEDState = LED_ON;
      Serial.println("  -> LED state: ON (ready state)");
      setPowerMode(ACTIVE); // Button active, need fast response
    } else if (isPartialLockout) {
      // In PARTIAL_LOCKOUT: only explicitly locked buzzers turn OFF
      if (isLocked) {
        currentLEDState = LED_OFF;
        Serial.println("  -> LED state: OFF (locked in PARTIAL_LOCKOUT)");
        setPowerMode(LOW_POWER); // Button locked, use low power mode
      } else {
        currentLEDState = LED_ON;
        Serial.println("  -> LED state: ON (not locked in PARTIAL_LOCKOUT)");
        setPowerMode(ACTIVE); // Button active, need fast response
      }
    } else {
      // In LOCKED state: all non-selected buzzers turn OFF
      currentLEDState = LED_OFF;
      Serial.println("  -> LED state: OFF (not selected in LOCKED)");
      setPowerMode(LOW_POWER); // Button locked, use low power mode
    }
    
    savedLEDState = currentLEDState;
    Serial.println("=== STATE SYNC COMPLETE ===");
    return;
  }

  // Handle LED commands for this node
  if (msg.node_id == NODE_ID && msg.msg_type == MSG_LED_COMMAND) {
    currentLEDState = (LEDState)msg.value;
    savedLEDState = currentLEDState; // Save in case of disconnection
    Serial.print("LED command received: ");
    Serial.println(msg.value);

    // Handle state-specific initialization and power mode transitions
    if (currentLEDState == LED_ON) {
      ledcWrite(LED_PWM_CHANNEL, 255);  // Full brightness
      blinkState = true;
      setPowerMode(ACTIVE); // Button active, need fast response
    } else if (currentLEDState == LED_OFF) {
      ledcWrite(LED_PWM_CHANNEL, 0);  // Off
      blinkState = false;
      setPowerMode(LOW_POWER); // Button locked, use low power mode
    } else if (currentLEDState == LED_BLINK) {
      // Start two-stage blink pattern
      isInFastBlinkPhase = true;
      fastBlinkStartTime = millis();
      lastBlinkTime = millis();
      setPowerMode(LOW_POWER); // Button locked (selected buzzer), use low power mode
    } else if (currentLEDState == LED_FADE) {
      // Initialize fade state
      fadeBrightness = 0;
      fadeDirection = 1;
      lastFadeTime = millis();
      setPowerMode(MINIMAL); // Disconnected, use minimal power mode
    }
  }
}

void onDataSent(const uint8_t *mac, esp_now_send_status_t status) {
  if (status == ESP_NOW_SEND_SUCCESS) {
    Serial.println("Button press sent successfully");
  } else {
    Serial.println("ERROR: Button press send failed");
  }
}

// ============================================================================
// BUTTON HANDLING
// ============================================================================

void handleButton() {
  int reading = digitalRead(BUZZER_BUTTON_PIN);

  // Check if button state changed
  if (reading != lastButtonState) {
    lastDebounceTime = millis();
  }

  // Only register press after debounce delay
  if ((millis() - lastDebounceTime) > DEBOUNCE_DELAY_MS) {
    // Button pressed (LOW due to pullup)
    if (reading == LOW) {
      // Send button press message
      BuzzerMessage msg;
      msg.node_id = NODE_ID;
      msg.msg_type = MSG_BUTTON_PRESS;
      msg.value = 1;
      msg.timestamp = millis();

      Serial.print("Button pressed! Sending message from node ");
      Serial.println(NODE_ID);

      // Send with retries
      for (int i = 0; i < MAX_RETRIES; i++) {
        esp_err_t result =
            esp_now_send(mainControllerMAC, (uint8_t *)&msg, sizeof(msg));
        if (result == ESP_OK) {
          break;
        }
        delay(RETRY_INTERVAL_MS);
      }

      // Wait for button release to avoid multiple presses
      while (digitalRead(BUZZER_BUTTON_PIN) == LOW) {
        delay(10);
      }
    }
  }

  lastButtonState = reading;
}

// ============================================================================
// CONNECTION MONITORING
// ============================================================================

void checkConnection() {
  unsigned long now = millis();
  bool wasConnected = isConnected;
  
  // Check if we've timed out
  if (isConnected && (now - lastHeartbeatTime > CONNECTION_TIMEOUT_MS)) {
    isConnected = false;
    Serial.println("Disconnected from controller (timeout)");
    
    // Save current LED state before entering disconnected mode
    savedLEDState = currentLEDState;
    
    // Enter breathing fade mode to indicate disconnection
    currentLEDState = LED_FADE;
    fadeBrightness = 0;
    fadeDirection = 1;
    lastFadeTime = now;
    
    // Enter minimal power mode for maximum battery savings
    setPowerMode(MINIMAL);
  }
}

// ============================================================================
// LED HANDLING
// ============================================================================

// Smooth breathing fade effect for disconnected state
// Uses PWM to gradually fade brightness in and out
void handleLEDFade() {
  unsigned long now = millis();
  
  // Update fade brightness at configured interval
  if (now - lastFadeTime >= FADE_INTERVAL_MS) {
    lastFadeTime = now;
    
    // Update brightness based on fade direction
    fadeBrightness += (fadeDirection * FADE_STEP);
    
    // Reverse direction at brightness limits
    if (fadeBrightness <= 0) {
      fadeBrightness = 0;
      fadeDirection = 1;  // Start fading in
    } else if (fadeBrightness >= 255) {
      fadeBrightness = 255;
      fadeDirection = -1;  // Start fading out
    }
    
    // Apply brightness using PWM
    ledcWrite(LED_PWM_CHANNEL, fadeBrightness);
  }
}

void handleLED() {
  unsigned long now = millis();
  
  switch (currentLEDState) {
  case LED_ON:
    // Solid on at full brightness using PWM
    ledcWrite(LED_PWM_CHANNEL, 255);
    break;

  case LED_OFF:
    // Off (zero brightness) using PWM
    ledcWrite(LED_PWM_CHANNEL, 0);
    break;

  case LED_FADE:
    // Breathing fade effect (for disconnected state)
    handleLEDFade();
    break;

  case LED_BLINK:
    // Two-stage blink pattern: 5Hz fast for 3 seconds, then 2Hz slow
    unsigned long blinkInterval;
    
    // Determine if we're in fast blink phase or slow blink phase
    if (isInFastBlinkPhase) {
      unsigned long elapsedTime = now - fastBlinkStartTime;
      
      if (elapsedTime >= FAST_BLINK_DURATION_MS) {
        // Transition to slow blink phase
        isInFastBlinkPhase = false;
        blinkInterval = BLINK_INTERVAL_MS;  // 2Hz (500ms)
      } else {
        // Stay in fast blink phase
        blinkInterval = FAST_BLINK_INTERVAL_MS;  // 5Hz (100ms)
      }
    } else {
      // Normal slow blink
      blinkInterval = BLINK_INTERVAL_MS;  // 2Hz (500ms)
    }
    
    // Execute non-blocking blink using PWM
    if (now - lastBlinkTime >= blinkInterval) {
      blinkState = !blinkState;
      ledcWrite(LED_PWM_CHANNEL, blinkState ? 255 : 0);
      lastBlinkTime = now;
    }
    break;
  }
}

// ============================================================================
// SETUP AND MAIN LOOP
// ============================================================================

void setup() {
  // Initialize serial for debugging
  Serial.begin(SERIAL_BAUD_RATE);
  delay(1000);

  Serial.println("========================================");
  Serial.print("BUZZER NODE ");
  Serial.println(NODE_ID);
  Serial.println("========================================");

  // Set CPU frequency for power optimization
  setCpuFrequencyMhz(CPU_FREQUENCY_MHZ);
  uint32_t actualFreq = getCpuFrequencyMhz();
  Serial.print("✓ CPU frequency set to ");
  Serial.print(actualFreq);
  Serial.println(" MHz");

  // Configure GPIO pins
  pinMode(BUZZER_BUTTON_PIN, INPUT_PULLUP);
  pinMode(BUZZER_LED_PIN, OUTPUT);
  digitalWrite(BUZZER_LED_PIN, LOW);

  // Configure GPIO wake capability for light sleep
  gpio_wakeup_enable((gpio_num_t)BUZZER_BUTTON_PIN, GPIO_INTR_LOW_LEVEL);
  Serial.println("✓ GPIO wake configured for button pin");

  // Initialize PWM/LEDC for smooth LED control
  ledcSetup(LED_PWM_CHANNEL, LED_PWM_FREQUENCY, LED_PWM_RESOLUTION);
  ledcAttachPin(BUZZER_LED_PIN, LED_PWM_CHANNEL);
  ledcWrite(LED_PWM_CHANNEL, 0); // Start with LED off
  Serial.println("✓ PWM/LEDC initialized for LED control");

  // Set custom MAC address
  WiFi.mode(WIFI_STA);
  uint8_t customMAC[6] = {0xAA, 0xBB, 0xCC, 0xDD, 0xEE, NODE_ID};
  esp_err_t macResult = esp_wifi_set_mac(WIFI_IF_STA, customMAC);

  Serial.print("Custom MAC address: ");
  for (int i = 0; i < 6; i++) {
    Serial.printf("%02X", customMAC[i]);
    if (i < 5)
      Serial.print(":");
  }
  Serial.println();

  if (macResult == ESP_OK) {
    Serial.println("✓ Custom MAC address set successfully");
  } else {
    Serial.println("✗ ERROR: Failed to set custom MAC address");
  }

  // Initialize ESP-NOW
  if (esp_now_init() != ESP_OK) {
    Serial.println("✗ ERROR: ESP-NOW initialization failed");
    return;
  }
  Serial.println("✓ ESP-NOW initialized");

  // Enable WiFi modem sleep for power optimization
  esp_err_t psResult = esp_wifi_set_ps(WIFI_PS_MIN_MODEM);
  if (psResult == ESP_OK) {
    Serial.println("✓ WiFi modem sleep enabled");
  } else {
    Serial.println("✗ WARNING: Failed to enable WiFi modem sleep");
  }

  // Register callbacks
  esp_now_register_send_cb(onDataSent);
  esp_now_register_recv_cb(onDataReceive);

  // Add main controller as peer
  esp_now_peer_info_t peerInfo = {};
  memcpy(peerInfo.peer_addr, mainControllerMAC, 6);
  peerInfo.channel = ESPNOW_CHANNEL;
  peerInfo.encrypt = false;

  if (esp_now_add_peer(&peerInfo) != ESP_OK) {
    Serial.println("✗ ERROR: Failed to add main controller as peer");
    return;
  }
  Serial.println("✓ Main controller added as peer");

  // Initial LED state: breathing fade (disconnected until first heartbeat)
  currentLEDState = LED_FADE;
  savedLEDState = LED_OFF;
  fadeBrightness = 0;
  fadeDirection = 1;
  lastFadeTime = millis();

  // Initialize connection state (start as disconnected, will connect on first heartbeat)
  isConnected = false;
  lastHeartbeatTime = millis(); // Initialize to current time

  // Start in minimal power mode (disconnected)
  currentPowerMode = MINIMAL;

  Serial.println("========================================");
  Serial.println("Buzzer node ready!");
  Serial.println("Waiting for controller heartbeat...");
  Serial.println("========================================");
}

void loop() {
  checkConnection();
  handleButton();
  handleLED();
  
  // Select sleep duration based on current power mode
  uint64_t sleepDuration;
  switch (currentPowerMode) {
    case ACTIVE:
      sleepDuration = LIGHT_SLEEP_DURATION_READY_US; // 50ms - fast button response
      break;
    case LOW_POWER:
      sleepDuration = LIGHT_SLEEP_DURATION_LOCKED_US; // 100ms - button inactive
      break;
    case MINIMAL:
      sleepDuration = LIGHT_SLEEP_DURATION_DISCONNECTED_US; // 200ms - disconnected
      break;
    default:
      sleepDuration = LIGHT_SLEEP_DURATION_READY_US;
      break;
  }
  
  // Enter light sleep with appropriate wake sources
  enterLightSleep(sleepDuration);
}

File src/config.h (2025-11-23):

#ifndef CONFIG_H
#define CONFIG_H

#include <Arduino.h>

// ============================================================================
// PIN ASSIGNMENTS
// ============================================================================

// Buzzer Node Pins
#define BUZZER_BUTTON_PIN 12 // Button input with internal pullup
#define BUZZER_LED_PIN 13    // LED output
#define BUZZER_SPEAKER_PIN                                                     \
  14 // Reserved for future speaker (not implemented in v1)

// Main Controller Pins
#define CTRL_BUTTON_CORRECT 25 // Correct answer button (with internal pullup)
#define CTRL_BUTTON_WRONG 26   // Wrong answer button (with internal pullup)
#define CTRL_BUTTON_RESET 27   // Full reset button (with internal pullup)

// ============================================================================
// TIMING CONSTANTS
// ============================================================================

#define BLINK_INTERVAL_MS 500 // LED blink rate: 2Hz (500ms on, 500ms off)
#define DEBOUNCE_DELAY_MS 50  // Button debounce time
#define RETRY_INTERVAL_MS 10  // ESP-NOW retry interval
#define MAX_RETRIES 3         // Maximum message retransmission attempts

// Connection monitoring
#define HEARTBEAT_INTERVAL_MS 2000 // Send heartbeat every 2 seconds
#define CONNECTION_TIMEOUT_MS 5000 // Consider node disconnected after 5 seconds
#define DISCONNECT_BLINK_INTERVAL_MS                                           \
  100 // Fast blink when disconnected: 10Hz (100ms on, 100ms off)

// PWM/LEDC Configuration for smooth LED control
// ESP32 LEDC peripheral provides hardware PWM for brightness control
#define LED_PWM_CHANNEL 0       // LEDC channel (0-15 available)
#define LED_PWM_FREQUENCY 5000  // PWM frequency in Hz (5kHz recommended to avoid flicker)
#define LED_PWM_RESOLUTION 8    // 8-bit resolution gives 0-255 brightness levels

// LED Fade Configuration for breathing effect
// Breathing effect creates smooth fade in/out during disconnected state
#define FADE_STEP 5             // Brightness increment per fade step (smaller = smoother)
#define FADE_INTERVAL_MS 20     // Time between fade steps (achieves ~2-3s per cycle)

// Two-stage Blink Configuration for pressed buzzer feedback
// Fast initial blink grabs attention, then transitions to slower sustained blink
#define FAST_BLINK_DURATION_MS 3000  // Duration of fast blink phase (3 seconds)
#define FAST_BLINK_INTERVAL_MS 100   // Fast blink interval: 5Hz (100ms on/off)

// ============================================================================
// COMMUNICATION CONSTANTS
// ============================================================================

#define SERIAL_BAUD_RATE 115200      // USB serial baud rate
#define MESSAGE_QUEUE_SIZE 10        // Maximum queued serial messages
#define ESPNOW_CHANNEL 1             // ESP-NOW WiFi channel (1-13)
#define SERIAL_INPUT_BUFFER_SIZE 256 // Buffer size for serial command input

// ============================================================================
// GAME CONFIGURATION
// ============================================================================

#define NUM_BUZZERS 4 // Total number of buzzer nodes

// ============================================================================
// POWER MANAGEMENT CONFIGURATION
// ============================================================================

// CPU frequency scaling for power optimization
#define CPU_FREQUENCY_MHZ 80  // Reduced from default 240MHz (saves ~40% CPU power)

// Light sleep durations for different power modes (in microseconds)
#define LIGHT_SLEEP_DURATION_READY_US 50000        // 50ms - Active mode (ready state, fast button response)
#define LIGHT_SLEEP_DURATION_LOCKED_US 100000      // 100ms - Low power mode (locked out, button inactive)
#define LIGHT_SLEEP_DURATION_DISCONNECTED_US 200000 // 200ms - Minimal power mode (disconnected, breathing LED)

// Response time guarantee for quiz fairness
#define MAX_BUTTON_RESPONSE_TIME_MS 50  // Maximum allowed button press to transmission latency

#endif // CONFIG_H

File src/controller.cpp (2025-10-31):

#include <Arduino.h>
#include <WiFi.h>
#include <esp_now.h>
#include <esp_wifi.h>
#include "protocol.h"
#include "config.h"

// ============================================================================
// GAME STATE MACHINE
// ============================================================================

enum GameState {
  STATE_READY,          // Waiting for first press, all buzzers active
  STATE_LOCKED,         // One buzzer pressed, all others locked out
  STATE_PARTIAL_LOCKOUT // Wrong answer given, that buzzer locked, others can try
};

GameState currentState = STATE_READY;
uint8_t selectedBuzzer = 0;        // 1-4, or 0 if none
uint8_t lockedBuzzers = 0;         // Bitmask: bit 0 = buzzer 1, bit 1 = buzzer 2, etc.
unsigned long lastPressTime = 0;   // For timestamp-based tie breaking

// Known buzzer node MAC addresses (custom MACs set on buzzer nodes)
uint8_t buzzerMACs[NUM_BUZZERS][6] = {
  {0xAA, 0xBB, 0xCC, 0xDD, 0xEE, 0x01},
  {0xAA, 0xBB, 0xCC, 0xDD, 0xEE, 0x02},
  {0xAA, 0xBB, 0xCC, 0xDD, 0xEE, 0x03},
  {0xAA, 0xBB, 0xCC, 0xDD, 0xEE, 0x04}
};

// Control button state management
bool lastCorrectState = HIGH;
bool lastWrongState = HIGH;
bool lastResetState = HIGH;
unsigned long lastCorrectDebounce = 0;
unsigned long lastWrongDebounce = 0;
unsigned long lastResetDebounce = 0;

// Serial message queue
String messageQueue[MESSAGE_QUEUE_SIZE];
int queueHead = 0;
int queueTail = 0;
int queueCount = 0;

// Connection tracking
unsigned long lastHeartbeatTime = 0;
unsigned long nodeLastSeen[NUM_BUZZERS] = {0, 0, 0, 0};
bool nodeConnected[NUM_BUZZERS] = {false, false, false, false};

// Serial command input
char serialInputBuffer[SERIAL_INPUT_BUFFER_SIZE];
int serialInputIndex = 0;

// ============================================================================
// SERIAL MESSAGE QUEUE
// ============================================================================

void queueMessage(const String& msg) {
  if (queueCount < MESSAGE_QUEUE_SIZE) {
    messageQueue[queueTail] = msg;
    queueTail = (queueTail + 1) % MESSAGE_QUEUE_SIZE;
    queueCount++;
  } else {
    Serial.println("WARNING: Message queue full, dropping message");
  }
}

void processMessageQueue() {
  while (queueCount > 0) {
    Serial.println(messageQueue[queueHead]);
    queueHead = (queueHead + 1) % MESSAGE_QUEUE_SIZE;
    queueCount--;
  }
}

// ============================================================================
// LED CONTROL
// ============================================================================

void sendLEDCommand(uint8_t nodeId, LEDState state) {
  if (nodeId < 1 || nodeId > NUM_BUZZERS) return;

  BuzzerMessage msg;
  msg.node_id = nodeId;
  msg.msg_type = MSG_LED_COMMAND;
  msg.value = state;
  msg.timestamp = millis();

  esp_now_send(buzzerMACs[nodeId - 1], (uint8_t*)&msg, sizeof(msg));
}

void updateAllLEDs() {
  for (uint8_t i = 1; i <= NUM_BUZZERS; i++) {
    if (currentState == STATE_READY) {
      // All LEDs on in ready state
      sendLEDCommand(i, LED_ON);
    } else if (currentState == STATE_LOCKED) {
      // Selected buzzer blinks, others off
      if (i == selectedBuzzer) {
        sendLEDCommand(i, LED_BLINK);
      } else {
        sendLEDCommand(i, LED_OFF);
      }
    } else if (currentState == STATE_PARTIAL_LOCKOUT) {
      // Selected buzzer blinks, locked buzzers off, active buzzers on
      if (i == selectedBuzzer) {
        sendLEDCommand(i, LED_BLINK);
      } else if (lockedBuzzers & (1 << (i - 1))) {
        sendLEDCommand(i, LED_OFF);
      } else {
        sendLEDCommand(i, LED_ON);
      }
    }
  }
}

// ============================================================================
// CONNECTION MONITORING & HEARTBEAT
// ============================================================================

void broadcastHeartbeat() {
  BuzzerMessage msg;
  msg.node_id = 0; // 0 = broadcast from controller
  msg.msg_type = MSG_HEARTBEAT;
  msg.value = 0;
  msg.timestamp = millis();

  // Send to each buzzer individually (more reliable than broadcast)
  for (int i = 0; i < NUM_BUZZERS; i++) {
    esp_now_send(buzzerMACs[i], (uint8_t*)&msg, sizeof(msg));
  }
}

void updateNodeConnection(uint8_t nodeId) {
  if (nodeId < 1 || nodeId > NUM_BUZZERS) return;
  
  unsigned long now = millis();
  bool wasConnected = nodeConnected[nodeId - 1];
  nodeLastSeen[nodeId - 1] = now;
  nodeConnected[nodeId - 1] = true;

  if (!wasConnected) {
    // Node reconnected
    Serial.print("RECONNECT:");
    Serial.println(nodeId);
  }
}

void checkNodeTimeouts() {
  unsigned long now = millis();
  
  for (uint8_t i = 0; i < NUM_BUZZERS; i++) {
    if (nodeConnected[i]) {
      if (now - nodeLastSeen[i] > CONNECTION_TIMEOUT_MS) {
        // Node timed out
        nodeConnected[i] = false;
        Serial.print("DISCONNECT:");
        Serial.println(i + 1);
      }
    }
  }
}

void sendStateSync(uint8_t nodeId) {
  if (nodeId < 1 || nodeId > NUM_BUZZERS) return;

  BuzzerMessage msg;
  msg.node_id = nodeId;
  msg.msg_type = MSG_STATE_SYNC;
  msg.timestamp = millis();
  
  // Pack game state into value field:
  // Bits 0-3: locked buzzers bitmask
  // Bits 4-6: selected buzzer (0-4)
  // Bit 7: game state mode (0=LOCKED, 1=PARTIAL_LOCKOUT)
  msg.value = lockedBuzzers | (selectedBuzzer << 4);
  if (currentState == STATE_PARTIAL_LOCKOUT) {
    msg.value |= 0x80; // Set bit 7 for PARTIAL_LOCKOUT
  }

  esp_now_send(buzzerMACs[nodeId - 1], (uint8_t*)&msg, sizeof(msg));
  
  Serial.print("STATE_SYNC:");
  Serial.print(nodeId);
  Serial.print(" (state=");
  Serial.print(currentState);
  Serial.print(", selected=");
  Serial.print(selectedBuzzer);
  Serial.print(", locked=0x");
  Serial.print(lockedBuzzers, HEX);
  Serial.println(")");
}

// ============================================================================
// GAME STATE HANDLERS
// ============================================================================

void handleBuzzerPress(uint8_t nodeId, uint32_t timestamp) {
  if (nodeId < 1 || nodeId > NUM_BUZZERS) return;

  // Check if this buzzer is locked out
  if (lockedBuzzers & (1 << (nodeId - 1))) {
    Serial.print("Buzzer ");
    Serial.print(nodeId);
    Serial.println(" is locked out, ignoring press");
    return;
  }

  if (currentState == STATE_READY || currentState == STATE_PARTIAL_LOCKOUT) {
    // Accept the press
    selectedBuzzer = nodeId;
    currentState = STATE_LOCKED;
    lastPressTime = timestamp;

    Serial.print("Buzzer ");
    Serial.print(nodeId);
    Serial.println(" pressed and locked in");

    // Send to PC
    queueMessage("BUZZER:" + String(nodeId));

    // Update LEDs: selected blinks, others off
    updateAllLEDs();
  } else if (currentState == STATE_LOCKED) {
    // Already locked, ignore subsequent presses
    Serial.print("System locked, ignoring press from buzzer ");
    Serial.println(nodeId);
  }
}
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

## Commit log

2025-10-31 working buzzer system with smooth connection blink
    [buzzer_node.cpp, config.h, controller.cpp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]
2025-10-31 led fixes
2025-11-23 battery saver test
    [Unnamed-Case.3mf, Unnamed-Lid.3mf, buzzer_case.FCStd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]
